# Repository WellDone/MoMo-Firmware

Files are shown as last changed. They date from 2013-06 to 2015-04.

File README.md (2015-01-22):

# WellDone MoMo Hardware and Firmware

A product of [WellDone.org](http://www.welldone.org).



Introduction and documentation available at https://momo.welldone.org

## License ##

Copyright 2015 WellDone International, all rights reserved.

MoMo hardware designs are released under the [CERN Open Hardware License v.1.2](http://www.ohwr.org/attachments/2388/cern_ohl_v_1_2.txt)

Firmware and software tools are released under the [GPLv3](http://www.gnu.org/licenses/gpl.html) Open Source license.

See the LICENSE file for more details.

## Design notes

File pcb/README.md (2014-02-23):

# MoMo Printed Circuit Boards
This directory contains all of the MoMo PCB files as well as scripts used to convert them into production data.
All boards must use EAGLE CAD for layout in order to be compatible with our production scripts.

## PCB Layout
The MoMo build system includes a set of python based tools used to automatically generate production files, BOMS 
and cost estimates from EAGLE board files.  In order for a board to be compatible with these scripts, it
must be made to conform with the following requirements.

EAGLE Attributes are used to tag each part and board with metadata that enables the scripts to look up
information on the part using the Octopart API and to generate a BOM.  Each part should have one of following attributes:

 * _DIGIKEY-PN_ - This should contain the Digikey part number for this part.  If there is not a digikey part number, is should
be left blank or non existent
 * _MPN_ - This is the Manufacturer's part number for the part.  Either MPN or DIGIKEY-PN must be set for every part on the board that
should be populated.
 * _MANU_ - The manufacturer's name.  If MPN is used to specify the part, MANU should be specified as well.
 * _FOOTPRINT_ - If the part does not have a standard SMD footprint link 0402, 0603, etc, they FOOTPRINT should be explicitly defined so
 that it can be used to create a BOM automatically.  If this is a through hole part, the footprint should be given as "Through Hole"
 * _DESC_ - If the part cannot have a generic description made for it (currently only works for Resistors, Capacitors and Inductors)
 then the explicit description should be given in this attribute.

###Assembly Variants
In order to save on PCB fabrication costs, sometimes a single circuit board will be made flexible so that it can be customized at assembly
time by simply change or not populating certain parts.  Each different way the same board can be assembled is called an Assembly Variant.

If a board has several assembly variants, this should be indicated by specifying certain attributes on the board.  An assembly variant can 
either populate a certain part, not populate a certain part or replace a part with a different one.  To do this, change the DIGIKEY-PN or MPN attribute for the part to contain -VARIANT where variant is the name of the assembly variant.  A part with only DIGIKEY-PN (or MPN) set will be assumed to be populated
in every assembly variant. A part with DIGIKEY-PN-VAR1 and DIGIKEY-PN-VAR2 will be populated only in Assembly Variants VAR1 and VAR2.  

A part with DIGIKEY-PN will be populated in every assembly variant except those that have a DIGIKEY-PN-VAR1 with an empty value.  This
means that the way to not populate a certain part in an assembly variant is to define its part number to be blank.  For library parts
that contain a default DIGIKEY-PN value that is not deletable, this is the only way to not populate a part in an assembly variant.

####Changing Part Values in Different Assembly Variants
Often a different assembly variant will not just populate or depopulate a part, but will change a part's value in order to achieve the desired effect.  
For example, a buck regulator design that can be configured to output either 3.6 or 5V depending on the assembly variant may require just changing the feedback resistor value.
In order to do this, the value should be specified as a VALUE attribute with the appropriate -VARIANT name.  So, if there are 2 assembly variants, 5V and 3V and a resistor is 10K in the 
5V version and 15K in the 3V version, the resistor should have the following two attributes:
VALUE-5V = 10K
VALUE-3V = 15K
The actual value of the part may be set to anything since it will be overriden by these attributes.  It is recommended that the actual part value be set to 'varies' so that the 
schematic's intent is not confusing.
###Global Attributes
Every board must define the following global attributes.  These should be defined on the Board, not the Schematic, under Edit->Global Attributes:

 * _[VARIANT]_ - for each assembly variant (if there is only one, nothing must be done) with value ASSY-VARIANT.  The attribute name is the variant name
 * _WIDTH_ - the width of the board (in inches)
 * _HEIGHT_ - the height of the board (in inches)
 * _REVISION_ - a tag specifying the revision level of the board
 * _PARTNAME_ - a name for the board that will be used to generate file names

###Required Configuration
In order to use these scripts you need to configure the location of the Eagle binary on your computer in /config/settings.local.json.  Use the template provided in:
settings.global.json

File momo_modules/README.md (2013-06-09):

### Code for individual MoMo component modules

All modules must implement the [Module Interconnect Bus (MIB)](http://github.com/WellDone/MoMo-Firmware/wiki/Module-Interconnect-Bus-(MIB\)) over I2C.

* `mainboard` (pic24) - The main controller module
* `field_service_unit` (pic24) - The USB<->I2C bridge used to service MoMos in the field.

### Shared Code

* `shared/picXX` - This code is specific to the picXX (i.e. pic12 or pic24) processor, but does not contain code specific to an individual module.
* `shared/portable` - This code (and anything it includes) should be able to run on EITHER an 8-bit pic12 or a 16-bit pic24.

### Source Directory Structure Guidelines

Source code sub-directories are categorized by the abstraction level and functionality goal of the code that lives in each directory.

* `Core` - This is where the core functionality lives.  This includes all top-level functionality and app-wide shared state/#define headers.
* `Debug` - This is code that deals directly with the processing of commands when the device is connected to a debugger / UART device.
* `Diagnostics` - Here there be monsters.  This is for self-test code and the like.
* `Modules` - Every .h/.c pair in Modules is responsible for managing a single, discrete hardware component.
* `Util` - As the name suggests, this is for pure-software utility functions.
* `main.c` - The program entrypoint of course.  This should remain as lightweight as possible.

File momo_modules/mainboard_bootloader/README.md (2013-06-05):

### WellDone MoMo Mainboard Firmware

* This code should be compiled using Microchip's [XC16](http://www.microchip.com/pagehandler/en_us/devtools/mplabxc/) compiler for 16-bit PIC24 devices.
* It has been tested on version 1.11 of the compiler.
* The approved build-compile-test system is to use [Ceedling](http://throwtheswitch.org/).  An introduction to using ceedling for TDD in embeded PIC environments can be found [HERE](http://spin.atomicobject.com/2012/10/22/getting-started-with-tdd-for-microchips-pics/)
* Unit and functional test scaffolding is forthcoming - we expect to support both the Microchip PIC Simulator and in-device physical test definitions.

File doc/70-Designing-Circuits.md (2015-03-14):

# Working with Printed Circuit Boards
The MoMo framework includes a number of tools that simplify the process of designing and assembling printed circuit boards.  These tools lets you automatically generated Bill of Materials documents, price your board at prototype and production quantities and generate all of the required production files for getting the board fabricated and assembled.  All of these products are built from your board layout file containing attributes describing all the required metadata.  This section details how to use the tools and how to design your boards to take advantage of the automatic MoMo PCB build system.

## Getting Started
There are a number of steps that take you from having a PCB layout to actually having that board assembled and in your hands (or those of your customers).  

- **(Supported)** You need to match all of the parts you chose with a component database and generate a Bill of Materials (BOM) document that you can use to buy all of the components for your board.
- **(Supported)** You may want to have multiple assembly variants of the same board, so you'll need a way to make appropriate BOMs and assembly drawings for each variant.
- **(Supported)** You need to generate gerbers and drill files from your board to send to the pcb fab for the board to get made.
- **(Supported)** You need to generate assembly drawings so that you can get the board populated with components from your BOM.
- **(Supported)** You need to figure out how much it will cost for your board in many different quantities and where you should buy your parts.
- (Support planned) You may want to generate a 3D model of your board to use to design the enclosure and make sure everything fits.
- (Support planned) You may need to generate pick and place instructions for automated assembly.

Each of these steps takes time and is error prone, contributing to the cost of your design by increasing the engineering time required to make it.  Included in `pymomo` is a suite of tools that automate each of these steps, reducing errors and saving time.  

In order to make this possible, you need to use a compatible ECAD program and you need to annotate your board with a minimum of metadata so that our automated tools know how to generate all of the required files from generic templates.  The way this annotation takes place depends on what ECAD system you use and is described for each supported program in one of the sections below.

### Required Board Metadata
Each board file is required to specify the following attributes, which are used at various points in the build process to generate output files like assembly drawings, BOMs and Gerbers. The specific way you need to set the attributes varies by ECAD program and is documented in the section on each supported program.

- Height: (number) The height (y dimension) of the board in the units specified in Dim_Units
- Width: (number) The width (x dimension) of the board in the units specified in Dim_Units
- Dim_Units: (text) The units for Width and Height (e.g. inches, mm)
- Company: (text) A string identifying the company or individual that made this board
- Revision: (text) A string specifying the version or revision number of this board.  This can be an arbitary string and is not forced to conform to any specific format.
- Fab_Template: (text) A string specifying what kind of board this is (two layer, 4 layer, etc).  It must correspond to the name of a template defined for your ECAD program, see the section on your ECAD program for the predefined templates.

### Required Component Attributes
In order to produced useful BOMs and quote board prices, we need to be able to match each component on the board with an online database of physical parts that could be purchased from a distributor.  This can be done in two ways.  Either you can supply a manufacturer and manufacturer's part number for a component, or you can supply a distributor's name, like Digikey or Arrow and their part number for the component.  These are the only attributes that are required per part.  

The rest of the information needed for generating BOMs can be looked up but if you would like to override it with your own values, you can define the following optional attributes that will be used instead of what is found in the database:

- Description: (text) a brief description of the component such as "PIC 24F16KA101 8-bit microprocessor"
- Footprint: (text) a text identifier for the type of package that the component comes such as SOT-23 or SMD 0402

Some standard packages are automatically inferred from information provided by the ECAD program and more will be added in the future.  If you don't like the wording of the package in the BOM, you can override it by using the FOOTPRINT attribute.  Not all online databases provide description information so it can be useful to set that attribute as well.

### When Are Identifiers Considered Identical?
A lot of the time there could be ambiguity over whether two words are the same.  For example, is "Digi-Key" the same distributor as "DIGIKEY"?  It's likely that the user intended for them to be the same, but they are not identical strings, making it difficult for a program to determine the user's intent.  In `pymomo.pcb` a consistent policy is applied to determine whether two text strings like manufacturer names or part numbers are identical.  First, all spaces, '_' and '-' characters are stripped out of both strings and they are converted to lowercase.  Then, these canonicalized strings are compared to see if they are identical.  So, "Digi-Key" matches "DIGIKEY" which also matches "DIGI KEY" but does not match "Digi,key".

### Supported Component Databases
Currently the only supported component database that can be used is [Octopart](http://octopart.com).  It is easy to add other databases and support is planned for Mouser's API as well. This means that to use the BOM matching features you currently need an Octopart API key (there's a free tier!).  `pymomo.pcb` looks for the key as an environment variable named `$OCTOPART_KEY`.  All results from any component database is cached for the maximum amount of time permitted by the TOS of the serivce to reduce latency and the total number of requests the program makes.  This caching process is transparent to the user and results returned from the cache are indistinguishable from those returned directly from the database.  

## Interacting with PCB Board Files
All of the objects that deal with circuit boards are defined in `pymomo.pcb` and accessible using the `momo` tool.  This section walks through some common tasks using the momo controller pcb as an example:

```shell
> ls $MOMOPATH/pcb/momo_modular/controller
controller.brd	controller.sch
```

### Matching Parts with an Online Database
```shell
> momo pcb CircuitBoard $MOMOPATH/pcb/momo_modular/controller/controller.brd match_status
True
```

`match_status` returns whether or not all of the parts on this board could be matched to an online database based on their embedded metadata.  You can get more details about the status of each part by using ```match_details```

```shell
> momo pcb CircuitBoard $MOMOPATH/pcb/momo_modular/controller/controller.brd match_details
Q1: Matched to a unique item
Q3: Matched to a unique item
Q2: Matched to a unique item
U5: Matched to a unique item
U4: Matched to a unique item
U1: Matched to a unique item
U2: Matched to a unique item
JP1: Matched to a unique item
C13: Matched to a unique item
JP2: Matched to a unique item
JP5: Matched to a unique item
JP4: Matched to a unique item
C15: Matched to a unique item
R13: Matched to a unique item
XT1: Matched to a unique item
C9: Matched to a unique item
C3: Matched to a unique item
C5: Matched to a unique item
C4: Matched to a unique item
R4: Matched to a unique item
C20: Matched to a unique item
R7: Matched to a unique item
R1: Matched to a unique item
D2: Matched to a unique item
```

This tells us that all of the parts were matched to exactly one physical part in the online database, indicating that there was no ambiguity in the match process and the board is ready for BOM generation.

### Looking up a Part 
You can look up any part on a board to see who sells it and how much it costs.  For example lets see what part U5 on the controller board does:
```shell
> momo pcb CircuitBoard $MOMOPATH/pcb/momo_modular/controller/controller.brd find U5
Part U5
 Manufacturer: MICRON
 MPN: M25PX80-VMN6TP
 Distributor: Digikey
 Distributor PN: M25PX80-VMN6TPCT-ND
 Package: SOP08 Package (0 pins, 8 pads)
 Location: (55.9816 millimeter, 19.6088 millimeter) rotated 90 degrees
 Description: M25PX80 1MB Serial Flash
```

It looks like this part is a flash memory chip.  Now let's see how much it costs and who sells it:

```shell
> momo pcb CircuitBoard $MOMOPATH/pcb/momo_modular/controller/controller.brd lookup U5
Manufacturer: Micron
MPN: M25PX80-VMN6TP
Description: NOR Flash Serial-SPI 2.5V/3.3V 8Mbit 1M x 8bit 8ns 8-Pin SO N T/R
Offers
  Seller: Verical
    Packaging: None
    Stock: 7500
    Minimum Order: 2500
    Breaks
      2500: 0.60000
  Seller: Digi-Key
    Packaging: Cut Tape
    Stock: 18208
    Minimum Order: 1
    Breaks
      1: 0.86000
      10: 0.78100
      25: 0.77120
      50: 0.76680
      100: 0.68540
      250: 0.67968
      500: 0.66960
      1000: 0.64548
  Seller: Digi-Key
    Packaging: Custom Reel
    Stock: 18208
    Minimum Order: 1
    Breaks
      1: 0.86000
      10: 0.78100
      25: 0.77120
      50: 0.76680
      100: 0.68540
      250: 0.67968
      500: 0.66960
      1000: 0.64548

 <output truncated>
```

The `lookup` function returns all of the sellers for a particular part known to the chosen online database.  

### Generating a BOM
Once a board has all of the required metadata, it can be used to automatically generate a BOM.  Currently, `pymomo` only supports generating excel style (.xlsx) BOMs since these are standard but support is planned for template based generation of BOMs in other formats.  First, let's make sure the BOM lines look right:

```shell
> momo pcb CircuitBoard $MOMOPATH/pcb/momo_modular/controller/controller.brd bom_lines
6 10K Resistor: ['R1', 'R2', 'R3', 'R5', 'R9', 'R18']
2 1 ohm Resistor: ['R4', 'R20']
5 100K Resistor: ['R6', 'R10', 'R11', 'R13', 'R19']
7 510K Resistor: ['R7', 'R8', 'R12', 'R14', 'R15', 'R16', 'R17']
8 100 nF Capacitor: ['C1', 'C2', 'C5', 'C10', 'C11', 'C12', 'C16', 'C17']
1 33 pF Capacitor: ['C3']
1 10 pF Capacitor: ['C4']
4 1 uF Capacitor: ['C6', 'C9', 'C19', 'C21']
2 18 pF Capacitor: ['C13', 'C14']
2 10 uF Capacitor: ['C15', 'C18']
1 22 pF Capacitor: ['C20']
2 Diode: ['D2', 'D3']
1 XC6504 Linear Regulator 2.8V: ['U1']
1 PIC24FJ64GA306 Microcontroller: ['U2']
1 RN4020 Bluetooth 4.0 Module: ['U4']
1 M25PX80 1MB Serial Flash: ['U5']
1 Quartz Crystal (Radial Can): ['XT1']
1 6 Pin Vertical Male Header: ['JP1']
1 6-pin female R/A header: ['JP2']
1 MicroUSB-B Receptacle : ['JP4']
1 R/A Shrouded 2 pin connector: ['JP5']
1 N-Channel MOSFET 2N7002P: ['Q1']
2 P Channel MOSFET: ['Q2', 'Q4']
1 PNP Transistor: ['Q3']
```

The `bom_lines` function returns a list of strings for each BOM line with the line's description and, quantity and reference designators.  If everything seems fine, you can export a BOM using:
```shell
> momo pcb CircuitBoard $MOMOPATH/pcb/momo_modular/controller/controller.brd export_bom $OUTPUT_FILE --format excel
```

`$OUTPUT_FILE` should be the path to the excel file that you want to generate.  If there are any errors or warnings in the process of generating the BOM they are noted in the excel file by default to make sure that you don't accidentally get a bad BOM.

### Checking For Errors
The program keeps track of any missing required attributes that it finds as well as common mistakes and can report these to you using the `get_errors` and `get_warnings` functions, which both return a list of strings.

```shell
> momo pcb CircuitBoard $MOMOPATH/pcb/momo_modular/controller/controller.brd get_errors
ERROR on attribute/part company: Attribute was empty or not defined
ERROR on attribute/part units: Attribute was empty or not defined
```

Here the system is telling us that we forgot to define a company and dim_units attribute on our board. In generated BOMs, the spots where the information is needed will be filled with obvious placeholder values until we fix this.  The program does its best to work around any missing information but always makes a note of it so that you know what it's doing.

### Pricing Parts and Boards
If you want to figure out how much a certain part costs at various quantities, you can use the `price` function.  For example, to figure out how much part U5 costs for 1 unit from Digikey, you can do:

```shell
> momo pcb CircuitBoard $MOMOPATH/pcb/momo_modular/controller/controller.brd require_distributor Digikey price U5 1
$0.86 from Digi-Key as Custom Reel
```

More information on setting requirements about what types of sellers can be used to generate prices is discussed in the section on Creating a Price Model.  We can just as easily figure out how many 1000 parts would cost (including any saving due to price breaks).

```shell
> momo pcb CircuitBoard $MOMOPATH/pcb/momo_modular/controller/controller.brd require_distributor Digikey price U5 1000
$0.65 from Digi-Key as Custom Reel
```

To figure out how many an entire board costs, you can use the `detailed_prices` function.  For example, let's say that we want to buy enough parts for 10 boards from Digikey with 10% excess to account for assembly losses.  Since it's a small number of units, we don't want to consider any Digi-Reel custom reels.  It's most clear to specify the price requirements one at a time, we start by opening a momo shell and specifying our requirements:

```shell
> momo pcb CircuitBoard $MOMOPATH/pcb/momo_modular/controller/controller.brd
(CircuitBoard) require_distributor Digikey
(CircuitBoard) exclude_packaging "Custom Reel"
(CircuitBoard) detailed_prices 10 10
P Channel MOSFET: $4.32 from Digi-Key as Cut Tape
1 ohm Resistor: $0.64 from Digi-Key as Cut Tape
Diode: $3.76 from Digi-Key as Cut Tape
10 pF Capacitor: $0.13 from Digi-Key as Cut Tape
510K Resistor: $1.06 from Digi-Key as Cut Tape
RN4020 Bluetooth 4.0 Module: $88.40 from Digi-Key as Tray
10K Resistor: $0.92 from Digi-Key as Cut Tape
10 uF Capacitor: $3.42 from Digi-Key as Cut Tape
18 pF Capacitor: $0.48 from Digi-Key as Cut Tape
XC6504 Linear Regulator 2.8V: $3.91 from Digi-Key as Cut Tape
100 nF Capacitor: $2.02 from Digi-Key as Cut Tape
6-pin female R/A header: $7.26 from Digi-Key as Bulk
MicroUSB-B Receptacle : $4.33 from Digi-Key as Cut Tape
1 uF Capacitor: $2.64 from Digi-Key as Cut Tape
PIC24FJ64GA306 Microcontroller: $32.20 from Digi-Key as Tray
Quartz Crystal (Radial Can): $1.75 from Digi-Key as Bulk
PNP Transistor: $0.95 from Digi-Key as Cut Tape
33 pF Capacitor: $0.13 from Digi-Key as Cut Tape
N-Channel MOSFET 2N7002P: $1.35 from Digi-Key as Cut Tape
22 pF Capacitor: $0.13 from Digi-Key as Cut Tape
6 Pin Vertical Male Header: $2.05 from Digi-Key as Bag
M25PX80 1MB Serial Flash: $7.81 from Digi-Key as Cut Tape
R/A Shrouded 2 pin connector: $1.53 from Digi-Key as Bulk
100K Resistor: $0.76 from Digi-Key as Cut Tape
(CircuitBoard) quit
```

If we don't care about the details of how much each part costs but just want the total price, we can use the `total_price` function

```shell
momo pcb CircuitBoard $MOMOPATH/pcb/momo_modular/controller/controller.brd total_price 100 0
total: 1290.11
unit: 12.90
```

### Creating a Price Model
Price a board is a little complicated.  Each part could come from several distributors and each distributor has a finite amount of stock.  Parts come in various kinds of packaging as well like Reels, Cut Tape and Trays.  Part of pricing a board is setting up preferences for which distributors to buy from and what kinds of packaging to look for or avoid.  The set of requirements you have for sellers to be considered valid is called the Price Model by `pymomo.pcb`.  You can build it up little by little using the following functions:

```
exclude_distributor
require_distributor
exclude_package
require_package
require_stock
```

The `require_*` and `exclude_*` functions respectively whitelist and blacklist certain distributors and packaging types.  For example if you call:

```
(CircuitBoard) exclude_distributor Mouser
(CircuitBoard) require_package "Cut Tape"
```

Then you are saying that you only want to look at prices that come in Cut Tape and are not from Mouser.  You can also choose to only show prices where there is enough stock to cover your entire order from a single distributor using the `require_stock` function.  If you make a mistake, you can clear the current Price Model and start over using `clear_pricemodel`. The Price Model is a property of the CircuitBoard context that created it and will apply to all future pricing requests on that CircuitBoard until it is cleared.  

### Generating Production Files for Fabrication and Assembly
Once you have your board file tagged with all of the required metadata as described in the section on Supported ECAD Programs, you can use `pymomo.pcb` to automatically generate production files (Gerbers, Excellon Drill Files, Assembly Drawings and BOMs) for fabrication and assembly.  To do so, just create a CircuitBoard object and call `generate_production` passing the name of the directory you would like to create to contain all of the fabrication and assembly files.  For example,

```shell
$ momo pcb CircuitBoard $MOMOPATH/pcb/momo_modular/controller/controller.brd generate_production ~/controller
$ ls ~/controller/fabrication/
README.txt	controller.crm	controller.plc	controller.stc
controller.cmp	controller.drd	controller.sol	controller.sts
$ ls ~/controller/assembly/
BOM_controller.xlsx	controller.ps
```

The created production files include:

- GERBER format files for each layer on your board
- A README.txt that contains descriptions for each gerber, your company, part name, revision, etc.
- A BOM for your board
- An assembly drawing
- A zip file containing all of the fabrication (<part name>_fab.zip) related files for uploading to your board house.

### Templates Used for Production Files
In order to generate production files, you need to embed information into your board about the layers that you want generated.  For example, is your board a standard 2 layer design with top and bottom copper and soldermask and a top silkscreen or do you want a 4 layer board?  This is done by embedding a fab_template attribute into your board as described in the section on your particular ECAD program.  The template name is used to look up how many Gerber layers to create and what logical layers to include in each gerber file.

## Supported ECAD Programs
The `pymomo.pcb` PCB build system is completely agnostic to where the information it needs comes from, so it does not depend per-se on what ECAD program you use to design your circuit.  However, it needs a way to extract the information from your board files.  We have built adapters that work automatically with the following popular ECAD programs.  If you use another program you could consider writing an adapter module to make it work with `pymomo.pcb`.  Pull Requests are always appreciated.

### EAGLE CAD
Eagle is a very popular schematic capture and layout program and is fully supported by `pymomo.pcb`.  The build system works with EAGLE .brd board files and to be suitable you need to annotate the boards using EAGLE attributes as described in this section.  You also need to be using a new enough version of EAGLE that uses their XML file format.  

#### Specifying Global Board Information
You need to set the following 'Global Attributes' on your Eagle Board (not the schematic, the board itself).  You can set an attribute using the menu item Edit -> Global Attributes.  The attributes are described in the above section on required attributes.  This section just lists the names that each attribute should have (all attributes in Eagle are stored as uppercase strings).

- HEIGHT: Board Height
- WIDTH: Board Width
- DIM_UNITS: Height/width units
- COMPANY: Your company or name
- REVISION: An identifying specifying the revision of this board.
- FAB_TEMPLATE: The template describing the layers on your board (i.e. two_layer, 4_layer, etc).

#### Specifying Multiple Assembly Variants
If your board has multiple assembly variants, you need to specify what they are by defining a Global Attribute (see previous section) that contains the name of each variant.  The names can be any string you want that forms a valid EAGLE attribute identifier. Each variant should be defined by creating an attribute whose name corresponds to that name of the attribute and whose value is 'ASSY-VARIANT'.  Remember that assembly variant names are not case sensitive.  If you only have one assembly variant nothing needs to be done.

For example, to define a board with two assembly variants (solar and battery), define two global attributes as follows:

```
SOLAR: ASSY-VARIANT
BATTERY: ASSY-VARIANT
```

You can specify assembly-variant specific part information by appending the assembly variant name to a part's attribute using a hyphen, so if you want to make a part that is populated in the SOLAR variant but not in BATTERY (e.g. the solar panel), you could define two attributes on that part as follows:

```
POPULATE-SOLAR: YES
POPULATE-BATTERY: NO
```

This part will be automatically included as a populated part when you deal with the SOLAR variant but will be listed as an unpopulated part in the BATTERY variant.  You can also specify default values that apply at all variants except when overridden by specifying the attribute without a variant extension.  So the above example could also be written as:

```
POPULATE: YES
POPULATE-BATTERY: NO
```

The default attribute applied to all assembly variants would be to populate the part but, only for the battery variant, it would be overriden to not populate the part.  The following per-component metadata can be overwritten in this way:
- VALUE
- POPULATE
- DIST
- DIST-PN
- DIGIKEY-PN
- MANU
- MANU-PN
- DESCRIPTION

#### Specifying Component Metadata
In order to support BOM generation and the creation of placement files and assembly drawings, each component on the eagle board file must have a minimum out of metadata that allows it to be matched with an online component database and the rest of the information looked up.  Specifically, you have to provide either a distributor's name and part number or a manufacturer's name and part number.  These are specified using Eagle attributes attached to each component *on the board file*.  The list of valid attributes is:

- DIST - a distributor's name that carries this part
- DIST-PN - the distributor's part number for this part
- DIGIKEY-PN - a shortcut that sets DIST=Digikey and DIST-PN to this value
- MANU - The manufacturer
- MPN - The manufacturer's part number
- POPULATE - [yes | no], whether this part should be populated.  All parts are assumed to be populated unless a POPULATE=no attribute is specified.
- DESCRIPTION - a short textual description
- FOOTPRINT - the footprint for this part (i.e. SOT-23, SMD 0402, Through Hole, etc)

You can override some of these values per assembly variant as described in the previous section.

#### Supported Fabrication Templates
Currently, only two layer boards are supported without extra configuration by specifying 'two_layer' in the FAB_TEMPLATE global attribute.  This will create a board with the following gerber layers (composed of the indicated EAGLE layers):

- Top Soldermask: ["tStop"]
- Top Silkscreen: ["Dimension", "tPlace", "tNames"]
- Top Solderpaste: ["tCream"]
- Top Copper: ["Top", "Pads", "Vias"]
- Bottom Copper: ["Bottom", "Pads", "Vias"]
- Bottom Soldermask: ["bStop"]

The assembly drawing is in PS format since that is what EAGLE supports exporting and it includes the following layers:
["tPlace", "tNames", "tDocu", "Document", "Reference","Dimension"]

You can create your own eagle templates and use them in your boards by editing the eagle.json file in the config directory of pymomo.

#### Finding Your Installed Eagle Version
If you are not using Mac OS X you need to add the EAGLE executable to your $PATH in order for `pymomo.pcb` to be able to find it and use it for generating fabrication files.  You don't need to do this for BOM generation since that is done by parsing the EAGLE board files directly. 

If you are using Mac OS X and you installed Eagle to the standard location using the EAGLE installer (/Applications/EAGLE-X.Y.Z) then you don't need to do anything.  Pymomo will find eagle for you and automatically use the latest version.  If you want to force pymomo to use a particular version then you can add that version to your $PATH and pymomo will preferentially use what it finds in the path over what it finds looking on its own.

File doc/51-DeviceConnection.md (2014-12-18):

## Programming Your MoMo
This section documents the process of getting the MoMo build environment set up and ready for hardware programming and testing.  The build system and support tools are cross-platform on Mac OS X, linux and Windows but are only tested extensively on Mac OS X and linux.  Bugfixes and patches are always gratefully accepted.  Windows users will need to install some supporting programs that are installed by default on Mac OS X and Linux, so read the [Windows Installation](https://github.com/WellDone/MoMo-Firmware/wiki/windows-installation) first.

###Step 1 - Clone the Repository
Make sure git is installed on your computer and then clone our repository and checkout the dev branch with the following commands:
```shell
git clone https://github.com/WellDone/MoMo-Firmware.git
git checkout dev
```

###Step 2 - Run Vagrant or Develop Locally
There are two options here.  You can either:

* Install [VirtualBox](https://www.virtualbox.org/) and [Vagrant](http://www.vagrantup.com/downloads.html) and then run `vagrant up` from the repository directory.  This will download a Virtual Machine (VM) (note: the initial download is large) and provision it with all of the development requirements.  Subsequent steps below can be run through `vagrant ssh` which creates a virtual shell connected to the running VM.  At this point everything should be set up for you.
* OR Install the development dependencies locally.  There may be some idiosyncracies to work through, but you should be able to mostly follow the instructions [here](http://www.github.com/WellDone/MoMo-Firmware/wiki/Development-Dependencies).

### Looking Around
```shell
> ls
config  doc  momo_modules  pcb  README.md  tools
```

A brief overview of what is what:

- config - reference information about pcb layouts and build constants.  Templates for module skeleton code is stored here as well
- doc - assorted datasheets and reference information.  Not terribly well organized currently
- momo_modules - all module firmware is stored under these directories.  momo_modules/shared contains shared library code.  Other directories correspond to a single firmware image each.
- pcb - all circuit board
- tools - all of the support infrastructure is stored in the tools directory.  You should add tools/bin to your PATH for easy access to the support tools.  Most of the build system is implemented as a python package pymomo which lives in tools

### Step 3 - Required Configuration
Make sure `gpsim` and `sim30` are in your PATH by running `which gpsim` and `which sim30`.  If you need to use the pcbtool hardware support program, you'll also need `eagle` ([Eagle Cad](http://www.cadsoftusa.com/)), but if not it isn't required.

### Checking that Everything Works
Assuming that you added tools/bin to your PATH variable, you can use the modtool program to talk to a connected MoMo unit.  Plug in your MoMo FSU into a USB port and plug the other side into a MoMo unit.  Power the MoMo unit and you should see a green light illuminate on the FSU.  Usually the momo tools will be able to guess which port your MoMo is plugged into, if not you will need to know the device or com port that corresponds to the MoMo FSU.  

On linux it is probably:
```shell
/dev/ttyUSB0
```

On Mac OS X is is probably:
```shell
/dev/tty.usbserial.SOMETHING
```

On Windows is is probably COM2 or COM3 depending on how many other serial ports you have.  If you are using cygwin (which we don't recommend), then the serial port will show up probably as something like:
```shell
/dev/ttyS2
```

**Note:**  On OS X Mavericks, apple broke FTDI USB-Serial adapter support so you need to implement the workaround described here to install a working driver: http://forum.arduino.cc/index.php?topic=198539.0

If you need a driver for the MoMo FSU, it uses the FTDI 230X chip which has drivers here:
http://www.ftdichip.com/FTDrivers.htm

In what follows, _PORT_ will refer to the device or COM port as listed above that corresponds to your computer.  Try to access the MoMo and list all of its attached modules to make sure everything is working using the command below: 

```shell
modtool list
0: pv_mod
1: Whatever
2: Something else
```

**Note:** Windows users may need to add 'python' in front of commands like 'modtool' in order to be recognized.

If the command finishes without error, you are completely set up.  If it throws an exception then it was not able to guess your COM port correctly and you'll have to specify it explicitly, i.e.:
```shell
modtool list -p PORT
0: pv_mod
1: Whatever
2: Something else
```

### Step 4 - Read up on how to use all of the tools
There is documentation for all of the support tools that help you use MoMo.  Read about them in the [tools section](#tools)

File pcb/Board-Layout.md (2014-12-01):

# Circuit Board Layout Guidelines
This document specifies rules and best practices for laying out and routing MoMo circuit boards.  It should be followed for all MoMo boards.  Additions to this document will be made as new guidelines are needed or board specifications change.

## Feature Sizes
- All silkscreen label text should be size 32 mils in EAGLE.  This is large enough to be legible but not so large as to make placement too difficult.
- Minimum trace/space is 6 mil.  When possible, route with larger trace/spaces but that only really makes sense if you can route the entire board with larger traces.  Power containing traces should be sized according to power demands but at least 12 mils.

## Fixed Locations
Screw holes are required on the short edge of each MoMo module for proper assemble.  The holes should be .132" in diameter and spaced .128" in from the edge of the boards.  The should be spaced 1.1" apart from each other.  There will be a nylon standoff around the screw hole, meaning that the exclusion are around the screw hole is: 0.25" in diameter.  The two sets of holes should be 3.744" away from eachother center to center.  Given a 2" long module, that gives 0.128" away from the module edge.

## Miscellaneous

- All capacitors unless required should be 0402 from Eagle's RCL library C_US 0402K (Kemet for reflow soldering)
- All resistors should be MLCC 0603 standard 1% chip resistors unless other specs are required.

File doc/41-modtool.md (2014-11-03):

##modtool - Working with MoMo hardware modules

modtool is a program that sends commands to MoMo hardware modules and allows you to test them, debug them and program them.
It is written in python and all of its functionality is built on top of the pymomo.commander library.  If you are comfortable
in Python and looking to script your MoMo module, you should jump directly to using pymomo.commander in Python scripts.  If
you are looking for a command line application to simplify common MoMo related tasks, modtool is right for you.  Modtool
runs equally well on Mac OS X, Linux and Windows provided that you have installed all of its library dependencies.

### Introduction
modtool can do the following things:
 * Reprogram any MoMo module with new firmware
 * Run premade hardware testing scripts on any MoMo module
 * List attached modules and interact with them
 * Configure any MoMo module
 * Debug MoMo modules
 * Dump MoMo sensor or system logs

### Using Modtool
modtool is a command line program that lives in tools/bin.  If you have added tools/bin to your $PATH, you can run modtool
by executing:

```shell
$ modtool help
```

All of the modtool commands are documented in the internal help system, which can be accessed by using:

```shell
$ modtool help subcommand
```

### Connecting Your Hardware
Using modtool requires that you connect your MoMo device to your computer using a bridge between your computer
and the MoMo bus (MIB).  This could be done using a MoMo Field Service Unit (FSU) that connects to the MoMo and
to the USB port of your computer, or it could be done over bluetooth.  In either case, your fsu will show up as a
COM port and modtool interacts with the FSU by sending serial commands to that COM port.  Modtool will try to guess
which COM port your FSU is plugged into but if it cannot do so for some reason (like you have multiple virtual COM ports),
then you will have to specify the correct port.  You can do this by passing a -p <COM PORT or device file> parameter to
modtool.  

To verify that everything is working, attach your MoMo to the computer and run:
```shell
$ modtool list
```

If the command finishes correctly, your MoMo is correctly attached and modtool can find it.  If there is a communication error,
try passing the correct COM port.  On linux this could look like:
```shell
$ modtool list -p /dev/ttyUSB0
```

On Windows it could be:
```shell
$ modtool list -p COM3
```

You will need to replace those port identifiers with the correct ones for your system.  Once you have verified connectivity, 
you can use all of modtool's features to interact with your MoMo device.

### Modtool Commands

#### Listing and Describing MoMo modules
Each MoMo unit is composed of various boards that all perform specific tasks.  You can see what boards are attached to your 
MoMo controller unit by using:
```shell
$ modtool list
```

To get more information about a given module use:
```shell
$ modtool info <INDEX>
```
where INDEX is the index for the module given in the result of the 'modtool list' command.

### Reflashing a Module
If you want to update the firmware code running on an attached MoMo module, you can do so using the modtool reflash command.
You will have to specify which module to reflash using either its name or its address.  You can find the names and addresses
of all the attached modules using the modtool list command.  To reflash a module by address use:
```shell
modtool reflash -a N <HEXFILE>
```

To reflash by name:
```shell
modtool reflash -n gsm_mod <HEXFILE>
```

The reflash command clears the controller's firmware cache to make sure there's room, pushes the hex file to the controller,
finds the module by either its name or address and then sends an RPC call to that module for it to reflash itself.  The command
waits for the reflashing to finish before returning.  Note that since the module cannot communicate during reflashing, the wait
time is just a timer based on the maximum time that the reflashing could take.  You should not remove power from your MoMo unit
or try to use it during the reflashing process.  Doing so will definitely cause the firmware to be programmed incorrectly and
could potentially brick the module.  It is, by design, very hard to brick a MoMo module however so you should be safe.

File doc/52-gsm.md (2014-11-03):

## Using the GSM module

This tutorial assumes that you have a programmed v5 GSM module and a working connection from your PC to the MoMo.  It will introduce the GSM module and outline steps for setting it up.

### Physical setup

There are a few steps required to prepare the GSM module for transmission:

- Attach an antenna to the u.FL connector.  Make sure the connector is pushed all the way down and try to avoid having the antenna cable traverse over any of the board electorics
- Insert a Micro SIM card into the SIM card slot - this may require cutting a full-sized SIM or using a SIM Card Punch
- Wrap the entire MoMo in paper (to prevent shorting) and then tin foil from the kitchen (to work around a known issue with GSM transmission RF feedback)

### Hardware RF Feedback Known Issue

With version 5 and earlier GSM hardware, there is a known issue which can cause GSM transmissions to fail.  The symptom exhibited is as follows:

When sending a GSM message, the entire MoMo may reset (you can determine that this has happened by looking at the system log) while openning the GSM module attempts to acquire a network signal.

This won't always happen, but it can cause some frustration when it does.  Luckily, there is a relatively simple workaround:

The issue occurs because the GSM module causes excessive RF feedback to overload the circuitry.  This can be avoided, interestingly, by wrapping the entire device in standard kitchen aluminum foil.  To prevent the foil from causing shorts, the MoMo should first be wrapped in a tube of paper so that none of the metal foil comes in contact with the PCB.

### Testing with GSMTool

There is a command-line program called `gsmtool` in tools/bin that can be used to interact with the GSM module.  This may eventually be replaced by the `momo` tool.

The following is the output of `gsmtool -h` which describes some of what the tool can do:

```
Usage:
    gsmtool COMMAND [ARGS...]
    gsmtool help [COMMAND]

Options:
    -h, --help  show this help message and exit

Commands:
    cmd            Tell the GSM modem to execute an AT command
    debug          Get debug info
    dump           Dump the modem's serial buffer (for debugging)
    help (?)       give detailed help on a specific sub-command
    msg            Send a text message with the content <text> to <dest>
    off            Turn off the GSM modem
    on             Turn on the GSM modem.
  ```
  
  To test that the module is set up and working properly, follow these steps. *NOTE* this assumes that the GSM module is at address 11, replace 11 with the address of the module according to the output of `momo controller enumerate_modules`.
  
  1. Turn on the module `gsmtool on -a 11`, this may take a few seconds.
  2. Check that the module turned on with `gsmtool debug -a 11`, the output should include `module_on: True`
  3. Run an AT command to check that the SIM card is installed correctly: `gsmtool cmd -a 11 AT+CPIN?`, output should be `+CPIN: READY`
  4. Run another AT command to check that the module was able to connect to the network: `gsmtool cmd -a 11 AT+CREG?`.  If the output is `+CREG: 0,2` then the module is still searching for the network, if it is `+CREG: 0,1` then it has successfully registered.  Anything else probably indicates lack of signal (see below) or a bad SIM card.
  5. Run `gsmtool cmd -a 11 AT+CSQ` to check the signal strength.  A sample ouput is `+CSQ: 31,0` - The second number should always be 0, higher is better for the first number (31 is a strong signal).
  6. Finally, run `gsmtool msg -a 11 <number> "<message>"` to send an SMS containing the text <message> to <number>.  For example: `gsmtool msg -a 11 +14155551234 "This is a test of the emergency alert system."`
  7. Check that the message was sent by running `gsmtool dump -a 11` and noticing that there are no errors, then running `gsmtool debug -a 11` and noticing that the module turned itself off.

### Setting up autonomous reporting

Sending SMS messages is all well and good, but that was a lot of steps.  Let's set up MoMo to send messages by itself.  The tool we will use this time is affectionately called `reportinator` and is used to configure the reporting settings on the MoMo controller.

The following sequence tells the MoMo to start reporting to +1-415-555-1234 every hour, using the default aggregate settings (Min and Max over the whole interval, Mean and Count for each step)

```shell
$ reportinator route +14155551234
(12) +14155551234
$ reportinator interval 5
5
$ reportinator start
```

### Configuring reporting settings

Running `reportinator -h` yields:

```
Usage:
    reportinator COMMAND [ARGS...]
    reportinator help [COMMAND]

Options:
    -h, --help  show this help message and exit

Commands:
    aggregates     Get or set the report aggregates.
    flags          Get or set the report flags.
    help (?)       give detailed help on a specific sub-command
    interval       Get or set the reporting interval.
    log            Manage the log of reports, succeeded and failed.
    parse          Parse a report in BASE64 format
    route          Get or set the destination address for reporting.
    send           Send a single report
    sequence       Get the current report sequence.
    start          Start reporting
    state          Get the current state of the autonomous reporting flag.
    stop           Stop reporting
    test
```

Here's an overview of the different settings and commands available:

#### Aggregates

The aggregation / reduce functions to run over each time step, as well as over the entire reporting interval.  Use `reportinator aggregates` to read the current settings, and `reportinator aggregates <step_agg> <bulk_agg>` to set them.  Aggregates are reported and set as integer numbers, but internally they are a bitset with the following possible values:

- 0b00000001 = Count
- 0b00000010 = Sum
- 0b00000100 = Mean
- 0b00100000 = Min
- 0b01000000 = Max

Therefore, an aggregate value of 1 reports only the count, a value of 4 reports only the mean, while a value of 99 reports Max, Min, Sum, and Count (that's 64 + 32 + 2 + 1).

#### Flags

These will probably go unused, but can be set to include static values in every report from this MoMo.  `reportinator flags` to read and `reportinator flags <value>` to write.

#### Interval

How frequently a report should be sent.  `reportinator interval` to read and `reportinator interval <value>` to set. Possible values are:

- 1 = Every Second
- 2 = Every 10 Seconds
- 3 = Every Minute
- 4 = Every 10 Minutes
- 5 = Every Hour
- 6 = Every Day (default)

#### Log

Interact with the report log stored in flash on the MoMo controller.  Possible sub-commands:

- `reportinator log read [<n>]` - Read the last `<n>` entries from the log.  If `<n>` is not specified, read all entries.
- `reportinator log count` - Get the total number of entries in the log
- `reportinator log clear` - Erase the log completely (use with caution)

#### Parse

This command does not interract with an attached MoMo, but rather takes a base64-encoded MoMo report as its first argument and outputs a human-readable version, i.e.:

```shell
$ reportinator parse AgwNAAAAugLAIQAAYQUSGMAhAAAAAGkBAABoAQAAaAEAAGgBAABoAQAAaAEAAGgBAABoAQAAaAEAAGgBAABoAQAAaAEAAGgBAABoAQAAaAEAAGgBAABoAQAAaAEAAGgBAABoAQAAaAEAAGgBAABoAQAAZwEAAA==
version: 2
sensor: 12
sequence: 13
flags: 0
battery charge: 3.79V
diag: 8640, 0
Interval type: hour
         step: 1
        count: 24
Global aggregates:
	count = 8640
	min = 0
	max = 0
Interval Aggregates:
           count    mean
             361       0
             360       0
             360       0
             360       0
             360       0
             360       0
             360       0
             360       0
             360       0
             360       0
             360       0
             360       0
             360       0
             360       0
             360       0
             360       0
             360       0
             360       0
             360       0
             360       0
             360       0
             360       0
             360       0
             359       0
```

#### Route

The destination SMS address for reports.  `reportinator route` to read and `reportinator route <number>` to set.  The number should be of the form `+<cc>xxxxxxxxxx`, i.e. `+14155551234`.  No punctuation or spaces, start with + followed by the country code and then the phone number.

#### Send

Artificially construct and send a report, right now.

#### Sequence

Read the current sequence number which will be embedded in the next report.

#### Start

Start sending reports automatically at the designated interval.

#### State

Read whether or not the MoMo is currently generating regular reports (possible results: `Enabled` or `Disabled`)

#### Stop

Stop sending reports automatically.

#### Test

Run a test on report construction functionality on the attached MoMo.

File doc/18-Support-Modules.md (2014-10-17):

## Field Service Unit

This unit is currently used to control, reflash, and debug MoMo units.  It acts as a bridge between the MoMo's MIB communication protocol and USB.

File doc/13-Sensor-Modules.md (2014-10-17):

## Sensor Modules

Sensor Modules collect information from the physical world around a MoMo.

### MultiSensor

This is the Hulk Hogan of sensor boards.  It can serve many different purposes, and contains circuitry for the following sensors:

- 1 pulse counter
- 3 voltage sensors
- 1 current sensor
- 1 pressure sensor (requires an additional pressure transducer IC component)
- 1 serial comm line

More information about the MultiSensor and how to use it coming soon.

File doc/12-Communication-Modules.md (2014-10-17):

## Communication Modules

A MoMo needs some way to talk with the outside world, so it needs a Comm module.

### GSM Module

This is the first communication module you will encounter.  It contains a quad-band GSM radio and requires a micro-SIM card as well as a uFL antenna.

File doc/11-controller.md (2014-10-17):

## The Controller

This is the brain of any MoMo unit, and is the only module that is absolutely required.  The controller module contains:
- A 16-bit PIC24 MCU.
- 1MB of Flash memory
- A battery connector (which expects 2.8-3.4V DC)
- A battery charging circuit (the charging port expects >100mA from a solar panel or USB charger)

Version 5 of the controller hardware, currently the top of the line, is pictured below.

(image needed)

In this picture, the white connector on the left is for the battery and the port on the right is (optionally) for the charging source.

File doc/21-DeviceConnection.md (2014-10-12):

## Programming Your MoMo
This section documents the process of getting the MoMo build environment set up and ready for hardware programming and testing.  The build system and support tools are cross-platform on Mac OS X, linux and Windows but are only tested extensively on Mac OS X and linux.  Bugfixes and patches are always gratefully accepted.  Windows users will need to install some supporting programs that are installed by default on Mac OS X and Linux, so read the [Windows Installation](windows-installation) first.

###Step 1 - Clone the Repository
Make sure git is installed on your computer and then clone our repository and checkout the dev branch
```shell
git clone https://github.com/WellDone/MoMo-Firmware.git
git checkout dev
```

###Step 2 - Run Vagrant or Develop Locally
There are two options here.  You can either:

* Install [VirtualBox](https://www.virtualbox.org/) and [Vagrant](http://www.vagrantup.com/downloads.html) and then run `vagrant up` from the repository directory.  This will download a VM (note: the initial download is large) and provision it with all of the development requirements.  Subsequent steps below can be run through `vagrant ssh` which creates a virtual shell connected to the running virtual machine.  At this point everything should be set up for you.
* OR Install the development dependencies locally.  There may be some idiosyncacies to work through, but you should be able to mostly follow the instructions [here](http://www.github.com/WellDone/MoMo-Firmware/wiki/Development-Dependencies).

### Looking Around
```shell
> ls
config  doc  momo_modules  pcb  README.md  tools
```

A brief overview of what is what:
* config - reference information about pcb layouts and build constants.  Templates for module skeleton code is stored here as well
* doc - assorted datasheets and reference information.  Not terribly well organized currently
* momo_modules - all module firmware is stored under these directories.  momo_modules/shared contains shared library code.  Other directories correspond to a single firmware image each.
* pcb - all circuit board
* tools - all of the support infrastructure is stored in the tools directory.  You should add tools/bin to your PATH for easy access to the support tools.  Most of the build system is implemented as a python package pymomo which lives in tools

### Step 3 - Required Configuration
This is only required if you want to use pcbtool to automate processing of circuit board designs.  You must edit the file config/settings.local.json to contain the path to your local copy of EAGLE.

```shell
> cat config/settings.local.json 
{
	"external_tools":
	{
		"eagle": "<INSERT PATH TO EAGLE HERE>",
		"gpsim": "/opt/pic/bin/gpsim"
	}
}
```

In order to use the unit testing infrastructure for pic12 code, you must also configure the gpsim path but this is not yet supported since we require a modified version of gpsim (to fix many bugs in the main codebase that we hit).  Our internal gpsim version will be released soon and then unit testing will be available for everyone.

### Checking that Everything Works
Assuming that you added tools/bin to your PATH variable, you can use the modtool program to talk to a connected MoMo unit.  Plug in your MoMo FSU into a USB port and plug the other side into a MoMo unit.  Power the MoMo unit and you should see two green lights illuminate.  Usually modtool will be able to guess which port your MoMo is plugged into, if not you will need to know the device or com port that corresponds to the MoMo FSU.  

On linux it is probably:
```shell
/dev/ttyUSB0
```

On Mac OS X is is probably:
```shell
/dev/tty.usbserial.SOMETHING
```

On Windows is is probably COM2 or COM3 depending on how many other serial ports you have.  If you are using cygwin (which we don't recommend), then the serial port will show up probably as something like:
```shell
/dev/ttyS2
```

**Note:**  On OS X Mavericks, apple broke FTDI USB-Serial adapter support so you need to implement the workaround described here to install a working driver: http://forum.arduino.cc/index.php?topic=198539.0

If you need a driver for the MoMo FSU, it uses the FTDI 230X chip which has drivers here:
http://www.ftdichip.com/FTDrivers.htm

In what follows, _PORT_ will refer to the device or COM port as listed above that corresponds to your computer.  Try to access the MoMo and list all of its attached modules to make sure everything is working:
```shell
modtool list
0: pv_mod
1: Whatever
2: Something else
```

If the command finishes without error, you are completely set up.  If it throws an exception then it was not able to guess your COM port correctly and you'll have to specify it explicitly, i.e.:
```shell
modtool list -p PORT
0: pv_mod
1: Whatever
2: Something else
```

### Step 4 - Read up on how to use all of the tools
There is documentation for all of the support tools that help you use MoMo.  Read about them:
* [[modtool|modtool]]

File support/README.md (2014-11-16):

##Support Files
These files are support for external tools that may require modification in order to work with MoMo.  Currently the only such tool is gpsim, which requires a patch in order to correctly simulate Enhanced Midrange PIC processors.  In order to apply the patch you need to download gpsim from svn, apply the patch.

This document assumes that you are checking out gpsim into the parent directory containing MoMo-Firmware.  If this is not the case you will need to specify
the path to gpsim_16lf1847_support.patch based on your system.

```shell
> mkdir gpsim
> cd gpsim
> svn checkout svn://svn.code.sf.net/p/gpsim/code/trunk -r 2281 .
<Lots of text>
> patch -p0 -i ../MoMo-Firmware/support/gpsim_16lf1847_support.patch
patching file src/14bit-hexdecode.cc
patching file src/14bit-instructions.h
patching file src/Makefile.am
patching file src/makefile.mingw
patching file src/p16f1847.cc
patching file src/p16f1847.h
patching file src/p1xf1xxx.cc
patching file src/p1xf1xxx.h
patching file src/pic-instructions.cc
patching file src/pic-processor.cc
patching file src/pic-processor.h
```

Now you need to follow the [instructions](http://gpsim.sourceforge.net/gpsim_svn.html) to build and install gpsim.  For reference, the current required commands are:

```shell
> libtoolize --force
> aclocal
> autoheader
> automake --force-missing --add-missing
> autoconf
> ./configure
> make
> sudo make install
```

Make sure you install gpsim into your $PATH correctly and you should be able to build pic12 unit tests.  As a test, navigate to the pic12_executive directory
and make sure you can build the tests:
```shell
> cd MoMo-Firmware/momo_modules/pic12_executive
> momo build -c
> momo build test
```

You need to have the pro mode compiler currently to build the pic12_executive.

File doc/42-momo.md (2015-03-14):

## momo (the command line tool)

```momo``` is a powerful command line tool that can be used to explore the pymomo python API and to interact with the momo hardware.  It is the most basic way to interact with the MoMo ecosystem.  The ```momo``` tool is based on the concept of hierarchical contexts which have one or more methods that can be called in that context.  This section details how to understand and use the ```momo``` tool at a basic level as well as advanced customization and usage at the end of the section.

### Quick Introduction
The python API that is used to interact with the momo hardware consists of a number of classes, some of which are proxy objects for hardware devices and others represent types and data on the computer.  As an example, consider interacting with a MoMo controller module.  There is a python class ```MIBController``` that represents the controller connected to the computer and internally converts all method calls on that object into RPC calls that are sent to the controller hardware and the response is presented as the result of the function call.  This lets you control the MoMo hardware as if you were just programming with a standard python object.  

The momo tool has two key concepts: contexts and methods.  A context is a container that has a number of methods.  So ```MIBController``` is a context.  Each context has a number of methods that it can execute.  When you run the momo tool, it lets you call any context's method from the command line.  Internally all of the arguments you pass on the command line are converted to python objects and the method (which is just a regular python method) is called with the result printed for you.  This provides an easy way to interact with any object in the pymomo API without needing to write a python script.  You can just write commands with the momo tool and have them automatically converted into python calls.

When you're ready to write your own scripts, there is a direct 1:1 mapping between ```momo``` commands and python statements, so it's trivial to explore the MoMo ecosystem using the ```momo``` tool and then write more advanced scripts in python once you get the hang of everything.  The system that makes this possible is ```typedargs```, a python framework for annotating functions and classes with additional information that lets the momo tool convert command line strings into typed python objects and validate that the data entered makes sense.

If you have a MoMo controller plugged into your computer, we can do an example to demonstrate.

```
> momo
(root) 
```

Upon executing the momo command with no arguments you're dropped into the root context and momo creates a REPL (Read-Eval-Print Loop) for you to work in.  You can explore what commands are available using tab completion.  Pressing tab twice shows all of the available commands in this context (powered by GNU readline so it works the same as in the normal shell).

```
(root) <TAB><TAB>
ControllerBlock  Simulator        build            help             quit       
HexFile          back             controller       import_types     
(root) 
```

These are the commands that are available to you at the root level.  To see more details, use the builtin ```help``` command:
```
(root) help
root

Defined Functions:
 - Simulator(string type)
   Generic interface for simulating embedded microprocessors.

 - import_types(path package, string module=None)
   Add externally defined types from a python package or module

 - controller(string serial='')
   Given serial port descriptor, create all of the necessary

 - build(args)
   Invoke the scons build system from the current directory, exactly as if 

 - ControllerBlock(path source)
   The metadata block in a pic24 controller firmware image.  This includes

 - HexFile(path source, integer wordsize, integer filewords, integer skip=1, integer cutoff=65535)
   A generalized container object for representing sparse memory views like those

Builtin Functions
 - quit: quit the momo shell
 - help [function]: print help information about the current context or a function
 - back: replace the current context with its parent
```

```help``` without any arguments prints short documentation on all of the available methods in this context.  To learn more about any particular method, use ```help <method>```.

```
(root) help controller

Given serial port descriptor, create all of the necessary
object to get a controller proxy module 

Arguments:
 - serial (string): the serial port to use
```

Notice how you see a docstring for the method drawn directly from the pymomo package as well as descriptions and types for any arguments that it accepts.

Now lets start interacting with the controller board.

```
(root) controller
(MIBController) help

MIBController
A python proxy object for interacting with the MoMo controller board.

Defined Functions:
 - reset(sync=True)
   Instruct the controller to reset itself.

 - current_time()
   Get the current time according to the controller's RTCC

 - sync_time()
   Set the time on the momo controller to the current system time.

 - read_log()
   Read the MoMo system log

 - enumerate_modules()
   Get list of all attached modules and describe them all

 - build_report()

 - clear_log()
   Clear the MoMo system log.

 - get_module(string name=None, integer address=None, force=False)
   Given a module name or a fixed address, return a proxy object

 - perf_counter(integer counter)

 - count_modules()
   Count the number of attached devices to this controller

 - get_report()

 - factory_reset()
   Instruct the controller to reset all internal state to "factory defaults."  Use with caution.

 - set_time(year, month, day, hours, minutes, seconds, weekday=0)
   Set the current time of the controller's RTCC

 - read_ram(integer address, string type=None, integer size=0)
   Read bytes from the controller ram starting at the specified address.  If a 

Builtin Functions
 - quit: quit the momo shell
 - help [function]: print help information about the current context or a function
 - back: replace the current context with its parent
```

Notice how the context changed from root to MIBController.  From now on any method we execute will be one defined in the MIBController class.  If you're done with a context and want to go back, use the builtin function ```back``` to destroy the current context and go back to its parent.  Technically, the list of contexts you've visited forms a stack so you can always pop the top context off and go back to the one before it using the ```back``` command.  

If you type back from the root context, ```momo``` will exit since there's no context to go back to.  Otherwise you can quit by typing ```quit``` in any context since its a builtin function that's always available like ```back``` and ```help```.

The core concept of ```momo``` is that if you know the python method you immediately know how to call it in ```momo``` and if you call a method using the ```momo``` tool you also know how to call it in python since the two are always linked.  The purpose of the ```momo``` tool is to provide an easy way to interact with the pymomo API without having to write python scripts for everything.

### Using momo without dropping into a shell

If you just want to type a quick command, you can do so without first creating a shell by entering the command into the initial command line used to invoke ```momo```.  For example, to reset a connected controller board just use:

```
> momo controller reset
```

Internally, momo parses the command line piece by piece so first it enters the controller context and then calls the reset method.  If the last method invoked does not create another context, the momo tool terminates since this is likely what you wanted.  If on the other hand, the last method does create a context then momo drops you into a shell in that context.  This lets you speed up access to contexts that you want to interact with for some time but require several commands to setup.  For example:

```
> momo controller
(MIBController) 
```

You can chain as many methods together as you like, so if you want to pull a system log from a MoMo controller and display it you could do:
```
> momo controller read_log display 
PERFORMANCE (2000-01-31 16:30:20) Periodic log of how often the microprocessor is asleep
 - Total Ticks: 23110
 - Sleeping Ticks: 22370
 - Number of prevented sleeps: 0
 - Tasks: 0x2356
CRITICAL (2000-01-31 16:30:20) The MoMo controller received a reset RPC and is resetting
CRITICAL (2000-01-31 16:30:20) The MoMo controller has been reset
CRITICAL (2000-01-31 16:30:20) The MoMo controller has been initialized
CRITICAL (2000-01-31 17:23:32) The MoMo controller received a reset RPC and is resetting
CRITICAL (2000-01-31 17:23:33) The MoMo controller has been reset
CRITICAL (2000-01-31 17:23:33) The MoMo controller has been initialized
PERFORMANCE (2000-01-31 17:23:40) Periodic log of how often the microprocessor is asleep
 - Total Ticks: 27576
 - Sleeping Ticks: 26890
 - Number of prevented sleeps: 0
 - Tasks: 0x2356
```

```momo controller read_log``` pulls the system log from the MoMo controller board and creates a SystemLog context with the information it receives.  This context supports the display method to show its contents, which is then invoked.  

### Running Commands on Startup

You'll likely find that you want to set up the momo tool to always initialize certain contexts everytime you create them.  For example, the SystemLog context requires commands adding LogDefinition files so that it knows how to parse the data that it's getting back from the MoMo controller.  The actual command that was executed in the last example was:

```shell
> momo controller read_log add_ldf mainboard/src/log_definitions.ldf add_ldf shared/pic24/src/log_definitions.ldf display
```

However, this is tiresome to write.  So you can create a configuration file that contains momo commands that are run whenever a certain context is created.  The format of the file is straightforward:

```
> cat ~/.config/momo_config.txt
[root]
import_types /home/timburke/Projects/MoMo-Firmware/momo_modules/shared/pic24/python/firmware_types

[MIBController.SystemLog]
add_ldf /home/timburke/Projects/MoMo-Firmware/momo_modules/mainboard/src/log_definitions.ldf
add_ldf /home/timburke/Projects/MoMo-Firmware/momo_modules/shared/pic24/src/log_definitions.ldf
```

The file should be called momo_config.txt and stored under the .config directory in your home folder on unix and in %APPDATA% on windows.  To Find where the config file should be stored on your system just run:

```
> momo --rcfile
/Users/timburke/Library/Preferences/momo_config.txt
```

The example shows the directory location on a Mac OS X system.

On all systems, the format of the momo_config file is the same.  It consists of a list of context patterns in brackets followed by initialization commands.  Whenever a context matching the pattern is created, the initialization commands are run.  A context pattern can be either a single context name like root for the root context or a hierarchy of contexts separated by dots.  For example, above we want to run a few add_ldf commands everytime a SystemLog is created by a MIBController.  If the SystemLog is instead created by another context, we don't want to modify it.

Adding commands under the root context will cause them to always be run when you invokve the ```momo``` tool.

### Adding Additional Types
If you create your own MoMo hardware modules or get them from other people, there will likely be additional proxy objects and types that will be useful for interacting with those modules but not contained in the core pymomo package.  The root context of ```momo``` has a method ```import_types``` that imports arbitrary types and makes them available for use in the momo tool.  It's usage is beyond the scope of this section though and will be detailed elsewhere.

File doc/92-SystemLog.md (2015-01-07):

# Understanding and Using the MoMo System Log
Each MoMo controller board has a nonvolatile system log that is used to log debug and error information as well as (in the future) for running hardware tests.  The log is stored in the external flash memory on the controller board as a circular buffer so, if it fills up, the oldest entry will be overwritten.  This document details how the system log is structured as well as how to interact with it and use it programmatically.

In order to be fast and general, log message strings are not embedded into the system log, instead a 32-bit hash is generated as a unique ID for each log message and that id is stored in the log.  Parsing the log back to string messages rather than message IDs requires having access to the Log Definition File that was used to compile the firmware code that emitted the log message.

## System Log Format
The system log is composed of a series of typed entries (RawEntry) of a fixed size (currently 16 bytes).  A log entry starts with a RawEntry containing the timestamp (accurate to the second) of the logging message as well as a 32-bit id number that corresponds with the message being logged.  It is followed by zero or more RawEntries that correspond with parameters that are associated with the log entry.  If parameters are too big to fit in a single RawEntry, they are automatically split across as many RawEntries as necessary.  Integer (16-bit) parameters are packed into a single RawEntry to save space when possible (7 per entry since 1 byte is taken up with entry type information).

### Parameter Types
Currently the supported parameter types are integer, boolean, string and blob.  Blob simply indicates that the data should be interpreted an an opaque array.  The corresponding log definition for this entry can specify how to interpret the blob and display its logical internal structure in a useful way.

## Using the System Log Programmatically (controller)
From controller code, which has direct access to the system log without making an RPC, you can use the following logging macros to log information.  First, make sure you include the appropriate headers:

```c
#include "system_log.h"
#include "log_definitions.h"
```

```log_definitions.h``` is a header file generated during the compilation process that contains a map between log statements and the 32-bit hash ids that are actually stored in the system log.  You should not edit it directly but rather edit the log_definitions.ldf file that is used to generate it.  

To log a message simply use:

```c
LOG_CRITICAL(message_id);
```

There is a also a corresponding ```LOG_DEBUG(message_id)``` macro that can be used.  If you wish to attach parameters to the log statement you can do so by following the initial LOG_**STREAM** statement with an arbitrary number of parameter log statements, for example:

```c
LOG_INT(10);
LOG_POINTER(ptr);
LOG_STRING("Hello world.");
LOG_ARRAY(array, length);
LOG_BOOL(true);
```

When the system log is read, parameter log statements are implicitly associated with the last message_id.

## Using the System Log Programmatically (other modules)
Remote logging from other modules is not yet supported by the system log though support is planned for this feature.

## Creating New Log Entry Types
Every log entry in the system must correspond with a log definition in a Log Definition (.ldf) file.  The format of this file is straightforward and just lists the name of the log statement, the message that corresponds with it, and any parameters that it expects.  The format is:

```
LogStatementName
"quoted string message"

- "Parameter name" [list of] type[, format format_name]
<zero or more parameter statements> 
```

An example with and without parameters is:

```
PowerOnNotice
"The MoMo controller has reset due to a power-cycle event"

DeviceResetNotice
"The MoMo controller has been reset"
- "Welcome mat" as string
- "Welcome number" as integer, format hex
```

The type should correspond to a known type in the typedargs type system and is used to interpret the binary data logged with the entry.  If format is 
specified, it should correspond to a defined formatting routine for the given type.  If no format is specified, then the default formatter for the type
is used. 

You can also define a log statement to contain a list of parameters with variable length but common type.  For example, to log the list of all tasks in the controller taskloop structure you could define a log entry as follows:

```
TaskLoopFullError
"The taskloop was completely full and a new task was added"

- "Tasks" as list of fw_task
```

The special syntax ```list of <type>``` defines this entry to consume all remaining logged parameters.  You can have at most one list per log entry and it must be the last parameter.  If you create an LDF file violating this rule, the build system will throw an error to let you know.

###Important Notes

- The 32-bit message id is formed from the low 32 bits of the MD5 hash of the LogStatementName, so if you change the LogStatementName, it will no longer hash to the same value and hence the system log reading functions will not be able to match it with the hash value stored in the system log.  *You should avoid* changing the name of existing log entries and instead just create new log entries.
- There is a very small, though nonzero probability that two Log Statement Definitions collide to the same hash value.  If this happens, the build system will throw an exception and you will have to modify the name of one of the definition names in order to fix the collision.  With 4 billion choices, this should not be too much of a problem.

## Reading the System Log
Using the momo tool is the easiest way to read the system log.  The most basic option would be to connect the momo to the computer and then use:

```shell
> momo controller read_log display
CRITICAL (2000-01-31 16:02:14) 0xF520EAFE
CRITICAL (2000-01-31 16:02:14) 0x67F94DC9
 - Hello world.
 - 10
CRITICAL (2000-01-31 16:02:14) 0x17CE2635
```

You can see each log enty with its stream as well as any parameters with which it was logged.  The log statement is displayed as a hex hash value because you haven't added any ldf files with which to interpet the log.  You can do so interactively by dropping into a momo shell:

```shell
> pwd
/home/timburke/Projects/MoMo-Firmware/momo_modules/mainboard
> momo controller read_log
(SystemLog) display 
CRITICAL (2000-01-31 16:02:14) 0xF520EAFE
CRITICAL (2000-01-31 16:02:14) 0x67F94DC9
 - Hello world.
 - 10
CRITICAL (2000-01-31 16:02:14) 0x17CE2635
(SystemLog) add_ldf src/log_definitions.ldf
(SystemLog) display
CRITICAL (2000-01-31 16:02:14) The MoMo controller received a reset RPC and is resetting
CRITICAL (2000-01-31 16:02:14) The MoMo controller has been reset
 - Welcome mat: Hello world.
 - Welcome number: 0xA
CRITICAL (2000-01-31 16:02:14) The MoMo controller has been initialized
```

Each module that contains logging statements should include a file named log_definitions.ldf in the src directory.  This is the file that should be included using the add_ldf directive. Note how the ldf file both lists the appropriate message to use with the log statement as well as how to interpret and display the parameters.  If you want to do this in one line you can use:

```shell
> momo controller read_log add_ldf src/log_definitions.ldf display
CRITICAL (2000-01-31 16:02:14) The MoMo controller received a reset RPC and is resetting
CRITICAL (2000-01-31 16:02:14) The MoMo controller has been reset
 - Welcome mat: Hello world.
 - Welcome number: 0xA
CRITICAL (2000-01-31 16:02:14) The MoMo controller has been initialized
```

You can add as many ldf files as you like in order to interpret all of the logging statements in the system log.  By default, if there is no log definition available, momo just diplays the raw parameters and the hash of the message id.

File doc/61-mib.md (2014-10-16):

# Module Interconnect Bus (MIB)
The Module Interconnect Bus is a shared remote procedure call type communication bus allowing for communication between different modules in the MoMo ecosystem. 

##Physical Specification
The MIB is an i2c bus.  Each module PIC will be connected via SCL and SDA lines that are open drain with pull up resistors on the controller board only.  The i2c bus will run at 100 KHz.  

##Message Structure
The i2c bus has a master-slave format.  The master controls SCL and sets the direction of data transfer.  It can either send or receive data from the slave.  Each complete message in the MIB protocol will correspond logically to a remote procedure call (RPC) where the master is executing a procedure on the slave and getting the return result.  This is summarized in Figure 1.


Figure 1

The master begins the transaction with the slave by sending an i2c start condition with the slaves address and write indicated.  It sends a packet specifying the feature and command, which uniquely determine the function the slave should execute.   At this point the slave searches for a handler function to handle that command and clock stretches until it has found one or determined that it does not support the command.

The master then sends another packet with the typed parameter list for the command.  The slave receives these and stores them in a buffer specified by the command handler found for the command.  The master then sends a repeated start with read indicated to read the return value for the command.  Upon receipt of this, the slave begins executing the command and clock stretches until it has finished, at which point the master reads at least one and up to two packets specifying the status of the executed command and its return value if there is one.

The master then sends a write packet with at least 1 byte to reset the slave according to the bus Slave Reset Protocol.

The master then sends an I2C stop condition to terminate the communication and both master and slave return to an idle state to await the next communication. 

##Packet Structure
All messages that go onto the wire are composed of packets.  A packet is a series of bytes beginning with an address and ending with a checksum.   It has the following format.  
```
Start or Repeated Start
Address + RW
Data byte 1
…
Data byte n
Checksum
```

###Checksum
The packet checksum is calculated as the 2’s complement of the sum of the data bytes in the packet, not including the address ignoring overflow.  The sum is calculated by using an unsigned 8 bit accumulator value initialized to 0 at the beginning of the packet transmission.  As each byte is transmitted over the wire it is added to the accumulator, ignoring overflow.  After the last data byte is transmitted, the accumulator is negated and 1 is added to it to form the two’s complement, which is then transmitted as the final byte of the packet.  

So a packet with N data bytes will transmit N+2 bytes (address + N data bytes + checksum).  

###Acknowledge Bit
The i2c protocol requires that an acknowledge (ACK) or not acknowledge (NACK) to be transmitted after each byte is transmitted on the wire.  What this bit means depends on the direction of the message.

####Master Writing to Slave
When the master writes 8 bits to a slave, it generates a 9th clock pulse for the slave to send it an acknowledge bit.  The slave should always send ACK.  ACK means that it received 8 bits, not that it knew what to do with them or that they were the bits it was expecting.  This is because the pic24 hardware i2c logic automatically acknowledges received bytes and only sends NACK if the receive buffer is full.  

####Master Reading from Slave
When the master reads from the slave, it generates 8 clock pulses to read 8 bits from the slave and then generates a 9th clock pulse to send an ACK/NACK bit to the slave.  It is very important that the master ACK every data byte from the slave and NACK the checksum byte.  This is because ACK for master reads means that the slave should continue sending bytes.  NACK means that the slave should stop sending bytes.  If the master does not NACK the last byte in the packet (the checksum byte always), the slave will think it should transmit another bit and will in some cases keep pulling SDA low waiting for a clock pulse.  This does not allow the master to control SDA and send a stop condition, causing a bus fault. 

##Protocol Layers
The MIB protocol can be thought of as composed of distinct layers: the i2c physical layer, the packet layer and the RPC layer.  The i2c physical layer controls bus access, and sends or receives bytes from the wire.  The packet layer sends opaque data packets + checksums and verifies the checksum.  The RPC layer composes packets and defines the overall flow of the transaction.

##Parameter Data Structure and Type
MIB supports the following logical parameter types: integer (8 or 16 bit), string and opaque buffer.  On the wire, there are only two wire parameter types (integer and opaque buffer).  The 4 logical parameter types are encoded into these two types in the manner described below.  

##Automatic Recovery from Transient Bus Errors
Every packet in the MIB protocol has a checksum so that the recipient can be sure it has been received without error.  However, this is not an error correcting code, so the recipient must ask the sender to resend the data until it is received correctly.  There are 4 points in the MIB protocol where data integrity is checked:
* When a command is sent (master->slave)
* When all parameters are sent (master->slave)
* When the command status is read (slave->master)
* When the return value is read (slave->master)

Note that the slave does not execute the command handler until it has verified that the command and parameters were received correctly so, if there is a checksum error from master->slave in either the command or the parameters, the master will send a Slave Reset and then begin the command again.  Because the RPC layer stores buffers the command, slave address and all parameters internally, it can retry the command without requiring the user code to do anything.  Also, since it is guaranteed that the command handler on the slave side was not run if the checksum failed, the master is free to reinciate the RPC without worrying that the command may not be idempotent.  

If the checksum fails from slave->master, the master will keep sending read indications in pairs of 2 and the slave will keep sending the same status and return value until the master stops sending reads, indicating that the checksum was correct.  Since the slave RPC layer buffers the return value from the command handler it ran as well as the return status, it can resend them freely without needing to consult usercode.  

Thus, once a MIB RPC has finished, we can be guaranteed that it completed correctly without a transient bus error.  

###Slave Return Value Transmission
Slaves always respond to read requests from the master with data according to the following protocol.  If the slave has received an even number of reads, it sends its return status.  If it has received an odd number of reads, then it sends its return value.  This allows the master to repeatedly query the return status and value until they are correctly received.  If the slave is asked to send a return value and it did not execute a command_handler that returned a value, then it will send 1 garbage byte which the master must ignore.  

```
Slave Read 1 - send return status (2 bytes)
Slave Read 2 - send return value or garbage (at least 1 byte)
...
Slave Read 2N+1 - send return status (2 bytes)
Slave Read 2N+2 - send return value or garbage (at least 1 byte)
```

##Slave Reset Procedure
A significant issue with the i2c protocol is that there is no resynchronizaton procedure.  If a slave misses one clock, it will be 1 bit out of sync and misinterpret all subsequent data.  An obvious solution is to have the slave key in on the i2c stop condition and reset itself to a known state when a stop is received.  However, the PIC24 and probable PIC12 do not interrupt when a stop is received :(.  As a workaround we define a bus-specific reset procedure for returning a slave to known state independent of the course of events that screwed it up.  

The reset procedure is based on the observation that in the normal MIB transaction flow, the master never sends a write after a read.  It writes a command, writes a parameter and then reads the return status and return value.  So, the slave can be sure that if it receives a write after having received a read in the same transaction that this is an exception and reset itself.  This is implemented by having the slave keep an internal counter of how many reads it has received in the transaction (num_reads).  If it receives a write and num_reads > 0, then it resets itself back to idle.  

Note that the master does not need to know how the slave got screwed up in order to reset it.  It can just send one read followed by one write and be sure that the slave will then be idle and ready to receive a command.

###Reset Procedure
```
Slave state unknown: num_reads = X >= 0
Master Sends Read (1 byte): num_reads = X+1 > 0
Master Sends Write (1 byte)
Slave resets itself 
```

##Master Logic Flowchart
Figure 2 below shows the complete MIB Master state machine including all error processing.  This shows error processing paths as well.


Figure 2

##MIB FAQ
This section is to document why certain decisions were made.  This is not to say that they are the best option and should not be changed or revisited, but rather that we should understand the considerations that drove their choice so that a potential replacement doesn't fall afoul of the same problem.

###Why are the parameters all sent as a single packet?
This is to allow for easy command resending.  Currently the parameters are all composed into a packet in the mib_buffer and sent.  We know that they all fit into the mib_buffer since they are sent as a single packet which is limited in size to the size of the mib_buffer.  If there is a problem sending the parameters (arbitration lost or checksum error), we still have them all in the mib_buffer so we can resend them without needing usercode to provide them again.  This means the usercode can assume that the process always succeeds.

###Why is there a return status and a return value?
The return value is a typed parameter defined by the specific command being called, which the MIB layer knows nothing about.  However there needs to also be a way to indicate whether the command was successfully called or to signal that the parameters need to be resent, for example.  The return status serves this purpose.  Also, the slave needs to tell the master how many bytes are in in the return value (which can be a buffer so its unknown apriori).  So the return status sends a length to tell the master how many bytes to read in for the return value.  This also allows for void return values (the return status has a length of 0).

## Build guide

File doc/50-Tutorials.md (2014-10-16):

# Tutorials
Several step-by-step guides to get you started.

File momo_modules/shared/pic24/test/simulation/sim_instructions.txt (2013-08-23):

LD pic24super             
LC build/test/TestBuild.out
IO NULL build/test/out.txt
RP
E

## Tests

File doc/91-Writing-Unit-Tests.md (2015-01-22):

# Writing Unit Tests
The MoMo build system supports unit testing of firmware code in order to ensure robust functionality.
There are two different systems in place for testing 8-bit and 16-bit code since the architectures are
very different.  The structure of the unit tests is the same but the available functionality is different
as will be discussed below.  8-bit unit tests are run on the [GNU PIC Simulator](http://gpsim.sourceforge.net).  16-bit
unit test are run on Microchip's free but proprietary simulator sim30.  We use a customized version of gpsim until 
upstream supports all of the features we need.  Read the Contributing section for instructions on how to install and
patch an appropriate version of gpsim.

## Unit Test Introduction
Unit tests should consist of a single file each (with possible support files that vary based on the unit test type)
and should be stored in the test subdirectory of the module to which they pertain.  In the examples in this document
we will consider the 8-bit module pic12_executive.  You can see the unit tests defined for this module:

```shell
$ cd momo_modules/pic12_executive
$ ls test   
support_bus_master.cmd          test_boot_address.as        test_find_handler.as
support_find_handler_mib.as     test_bus_checkparam.as      test_flash_write.as
support_i2c_slave_16lf1847.cmd  test_bus_master.as          test_i2c_slave.as
support_i2c_slave.cmd           test_bus_returnstatus.as    test_i2c_utils.as
support_i2c_slave_receive.cmd   test_bus_slave_16lf1847.as  test_no_appmodule.as
support_no_appmodule.as         test_bus_slave.as
test_basic.as                   test_call_handler.as
```

Each file with a name that begins with 'test_' defines a unit test and all other files are supporting files that
are included in their corresponding unit tests.

## Defining a Unit Test
All unit tests need to contain a header the describes the unit test.

```shell
$ head -n 4 test/test_call_handler.as
;Name: test_call_handler
;Targets: all
;Type: executive
;Description: Test to ensure that the find_handler function works 
```

The header must start with either a ';' for assembly test files on 8-bit processors or a '//' in C test files and it
must be at the top of the file.  Only whitespace is allowed before the header starts.  The header consists of a list
of Name: Value pairs, called test attributes, some of which are required and others are optional.

### Required Test Attributes
All tests must define the attributes Name, Targets, Type and Description as described below:

- *Name* The name of the test.  This must not contain any whitespace and should be unique among all of the tests for a given module

- *Targets* If this test should only be compiled for a subset of the target architectures that this module targets, you need to list that 
subset here as a comma separated list.  For example

- *Type* The type of unit test that this is.  There are various options that are valid only for 8-bit and others only for 16-bit.

```
Targets:16lf1823,16lf1847
```

This would only compile the test for the 16lf1823 and 16lf1847 targets of the module.  If a test should be compiled for each target, specify

```
Targets: all
``` 
- *Description* A description of what the test does.  Description is allowed to extend onto multiple lines if it is the last attribute defined
for the test.  It is recommended that Description be the last attribute in the attribute list.

### Optional Test Attributes (8-bit)
Some attributes are used to add additional functionality to tests.  The attributes supported on 8-bit unit tests are:

- *Additional* takes a comma separated list of additional filenames that are added to the test. Depending on the file extension the files are 
processed differently.  If a .as file is listed it is compiled along with the main test file and may contain additional code or anything else
that can be compiled in a .as file.  If a .cmd file is specified then it is used to create a custom command script to drive gpsim.  This lets
unit tests define stimuli for the test to respond to, for example.  See support_i2c_slave.cmd for an example.  Since the cmd file is appended to 
the normal (autogenerated) test script, it must end with the run command so that the test is actually executed.

- *Checkpoints* takes a comma separated list of tokens in the form symbol=value, where value is an 8-bit integer in decimal, hex or binary.  
Checkpoints define a sequence of actions that must complete in order for the test to be considered successful.  For an example see test_basic.as
in pic12_executive/test.  Checkpoints are discussed in more detail in the Using Checkpoints section.

- *Patch* takes a comma separated list of taken in the form old_symbol=new_symbol and patches the hex file under test so that the first 3 words of
the function specified by old_symbol are replaced with an unconditional goto to new_symbol, which is the replacement function.  This lets tests
hook other functions that they want to either mock or checkpoint.

### Optional Test Attributes (16-bit)
Fill this in as we write more 16-bit unit tests and build-out more features in the framework

## How 8-bit Unit Tests Work
All 8-bit modules are divided into two components: the executive and the application.  The executive takes the first ~1K of ROM of the processor
and the application takes the rest of the ROM.  Since these are small chips and the application code might be tightly coupled, it makes the most
sense to test it as a unit.  So, unit tests for applications work by replacing the executive portion of the firmware with the unit testing code
and keeping the entire application code as it would be in the real module.  Executive tests work in a similar way by replacing the application code
with the unit testing script.  This is done automatically by the build system.  

There are three types of 8-bit unit tests that must be specified in the Type attribute: executive, executive_integration and application.  Executive unit tests can only be 
defined for the pic12_executive.  All other application modules must define all of their tests as application tests.  By default, no module code is run before jumping directly to the unit test code except when executive_integration testing is specified.  ```executive_integration``` tests run through the complete executive startup code and run the unit test code as an application module.  This lets you test things that require a fully initialized mib12_executive.

### An Example Unit Test
FILL In this section

### Including Different Support Files on Each Architecture
Sometimes the same unit test code will run on multiple architectures, so you would like it to run on multiple architectures, but those architectures require different support files.  For example, if you want to test whether a certain pin triggers an interrupt, the test code is the same: did the interrupt get triggers, but what if the pin is in a different location on the different architectures.  The unit testing build code handles this in the following way.  When you specify an additional file like a .cmd file to pass commands to gpsim or a .as file to include in your unit test code, the build system internally looks for that file name appended with the architecture currently being targeted and if that file is found, will use it instead of a generic version.  

For example, say that you're targeting the architectures ```12lf1822/v1``` and ```12lf1822/v2```.  In your unit test you have an additional file include statement like the following. 

```
Additional: support_pinlocation.cmd
```

When building for the v2 architeccture, the build system parses your architecture string into a prefix list:

```
["12lf1822", "v2"]
["12lf1822"]
[""]
```

It then splits the support file prefix off and adds in the architecture prefixes, in order until it finds a file that exists.  So it looks for:

```
support_pinlocation_12lf1822_v2.cmd
support_pinlocation_12lf1822.cmd
support_pinlocation.cmd
```

Once it finds a match it stops.  If no match is found, it throws a BuildError.  On the v1 architecture, the build system looks for 
```support_pinlocation_12lf1822_v1.cmd``` first, so you can just specify two different support files and the build system will pull them in automatically for the right architecture without needing to create a separate unit test code file.

### Using Checkpoints Effectively
FILL In this section

## How 16-bit Unit Tests Work

## Miscellaneous Information

### How Unit Tests are Discovered by the Build System
Inside the SConstruct file that builds each module are commands to search for a test subdirectory and create unit tests from each file in that directory
whose name begins with test_.  Adding a unit test is as simple as defining a new test_*.{c,as} file in the test directory for the module you would like
to test.

## How To Run Unit Tests
Each module has a default target alias called test that builds all of the unit tests for that module

```shell
$ momo build test
```

## Seeing Unit Test Output
Unit tests are run on the simulator and produce a log of their activities.  This log is stored in build/test/output/logs for each module.  This log is
then parsed by the build system to determine if the test passed succesfully and the result is written to a '.status' file containing either the world
PASSED or FAILED.  Then the build system examines the status files for all of the tests for each target architecture and creates a summary file in
build/test/output called results.txt that summarizes the results.  For the pic12_executive module we have

```shell
$ cat build/test/output/results.txt
Test Summary

## Target 16lf1823_exec ##
9/9 tests passed (100% pass rate)

## Target 16lf1847_exec ##
10/10 tests passed (100% pass rate)

## Target 12lf1822_exec ##
12/12 tests passed (100% pass rate)
```

Test results are broken down per target and the logs for any tests that fail can be inspected in build/test/output/logs.  The status and log files are
named according to the test name and architecture: test_foobar@random_architecture.{log,status}.

The test results are also shown at the end of momo build test:

```shell
$ momo build test
<lots of text>
Test Summary

## Target 16lf1823_exec ##
9/9 tests passed (100% pass rate)

## Target 16lf1847_exec ##
10/10 tests passed (100% pass rate)

## Target 12lf1822_exec ##
12/12 tests passed (100% pass rate)
scons: done building targets.
```

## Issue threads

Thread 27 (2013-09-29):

Sensor-agnostic, communication-module-limited report formatting

amcgee, 2013-09-29:
Reports should be condensed and/or streamed to the comm module based on the limits of the communication format, and shouldn't need to be aware of which sensor is attached to the device.  This reporting format will also need to take into account the possibility that multiple sensors are reporting through a single comm stream, as well as that different users might have different verbosity/bandwidth-conservation tradeoff requirements.

amcgee, 2015-03-14:
Moving bandwidth limitation to a new issue

Closed 2015-03-14.

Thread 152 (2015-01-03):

Get Python Type System to Version 1.0

timburke, 2015-01-03:
pymomo now relies fairly heavily on a typing system for some of its functionality.  The type system supports the following features:

- Annotate function arguments with a type so that the can be validated and converted from strings
- Conversion routines for each type from string
- Validation routines for each type that are particular to that type
- Formatting and printing routines for displaying the type in a nice fashion

This functionality is used currently in the following places:

- momo tool to convert command lines into python function calls
- syslog to display the typed parameters associated with each system log entry
- debug variable reading to display typed variables from the controller during operation

The type system works well but several outstanding features and refactoring  would be useful before considering it stable.  The isue tracks progress on these features.

- [ ] Add return value typing on annotated functions and use the formatting information from the type to print it in the momo tool rather than the current custom printer for each function that doesn't want the default str() conversion printing behavior
- [ ] Add ability to inject types from other python modules dynamically so that users can define their own types and use them.
- [ ] Add config file to momo tool that lets you set up the environment with your custom types and other config routines to make calls to momo less verbose
- [ ] Write more general unit tests using pyunit and include
- [ ] Split typedargs into a separate reporsitory and installable python package (momobase?) along with exceptions.

amcgee, 2015-01-04:
Agree on most of these, couple questions:

1. Is a config file the right way to go?  Doesn't that make custom extensions more difficult?
2. Should typedargs and exceptions be a separated from pymomo (2 new repos) or should all of pymomo be together in a separate repo?

timburke, 2015-01-04:
Not sure on either.  For 2, we can keep it all together in a separate repository, my concern would be if it gets really big but I don't really have a preference on this.  Only thing for splitting out typedargs is that it doesn't rely on anything else in pymomo so it could be a standalone package that other people could use.  But I don't see a need to do that anytime soon so we could keep together.

For 1, I'm not set on a config file but here's the use case that I'm looking at.  There is a significant amount of information that momo (the tool) needs to know about a module in order to be able to interact with it in a pleasing way.  Currently this is:

- the module's python proxy object (now in pymomo/commander/proxy)
- the module's log statement definitions (this will be more clear after the PR but these define the types and specified formatting of all of the log entries so that momo can interpret the log data in a way other than just strings, numbers and binary blobs (now stored in the src directory of each module since it's also needed in the build process)
- the module's symbol map (needed for fetching variables from live modules via name, mapping addresses to symbols in log entries).  This is currently a byproduct of the build process for pic12 modules and a .map file for pic24 that I haven't yet processed into a usable object)

You'll need these three bits of information from each module you want to interact with.  Bit 1 could be constructed on the fly from inspecting the module's RPC endpoints but it won't be as nice as what you would get from a custom proxy object with annotated types, validation of arguments, added features and doc strings).  I think it would be good to have these all stored with each module so that there are no global dependencies, i.e. the mainboard directory contains everything you need to interact with the mainboard.  But this requires telling the momo tool about those proxy objects, log definitions and symbols.  This can all be done with calls in the momo tool itself and currently that's what I do for the log definition files but it's verbose to have to call those functions each time you open the tool.  So the idea I had was to have a .momorc file similar to .bashrc that is invoked whenever you run the momo tool and you could use to preload log definitions, symbol files and proxy objects for modules that you commonly use.  This shouldn't limit customizability because there's nothing special about our modules and someone's special modules that they make later and there's no magic in the config file.  It's just making momo calls you could make yourself but doing them for you so you don't have to everytime.

Does this make sense or do you have a thought for how we could achieve this in a better way?  I see this as a way of getting the proxy objects for the modules out of pymomo and into each module where they belong (I think) without sacrificing usability or customizability.

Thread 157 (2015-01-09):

Finish module reset functionality by toggling ALARM pin

timburke, 2015-01-09:
The momo controller resets the modules on the bus by toggling the ALARM pin low for 10 microseconds.  This is currently disabled on pic16lf1847.  Test hotplugging situations to see if there are ALARM pin transients and then enable this code on all of the modules so that the new GSM module has it.

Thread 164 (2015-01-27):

New system log appears to be broken

amcgee, 2015-01-27:
Running `momo controller read_log` throws the following error:

```
ValidationError: Buffer must be of length sizeof(GenericLogEntry) = 16 bytes
Additional Information:
buffer: 3=?(
```

Running clear_log and then read_log accesses the SystemLog momo context but running `momo controller read_log help` fails like so:

```
(SystemLog) help

SystemLog
A list of log entries from the MoMo system log

The MoMo controller keeps an ordered list of timestamped
logged events, which can contain arbitrary parameters.
This class encapsulates one such list and allows you to
access, filter and display the log entries.

Defined Functions:
Traceback (most recent call last):
  File "/usr/local/bin/momo", line 9, in <module>
    load_entry_point('pymomo==1.0.4', 'console_scripts', 'momo')()
  File "/usr/local/lib/python2.7/dist-packages/pymomo/scripts/momo.py", line 88, in main
    line, finished = shell.invoke(line)
  File "/usr/local/lib/python2.7/dist-packages/pymomo/utilities/typedargs/shell.py", line 267, in invoke
    return _do_help(context, line)
  File "/usr/local/lib/python2.7/dist-packages/pymomo/utilities/typedargs/shell.py", line 108, in _do_help
    print_dir(context)
  File "/usr/local/lib/python2.7/dist-packages/pymomo/utilities/typedargs/shell.py", line 84, in print_dir
    print " - " + annotate.get_signature(fun)
  File "/usr/local/lib/python2.7/dist-packages/pymomo/utilities/typedargs/annotate.py", line 128, in get_signature
    name = f.__name__
AttributeError: LogDefinitionMap instance has no attribute '__name__'
```

Finally, running `momo controller reset` and then `momo controller read_log` again results in the original ValidationError.

This is running controller firmware v4.1 from the latest dev branch on the newest hardware version.

amcgee, 2015-02-01:
This has been resolved.

Closed 2015-02-01.

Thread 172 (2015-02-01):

GSM module can sometimes cause MoMo to be reset while attempting to register

amcgee, 2015-02-01:
This seems to be caused by poor network conditions and/or bad antenna positioning.  This was causing memory corruption errors before the log initialization order fix was introduced.

timburke, 2015-02-01:
This is bad.  I'll need to connect an oscilloscope and see what's going on.

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

amcgee, 2015-02-01:
Agreed

amcgee, 2015-03-14:
We've determined that this is an RF feedback issue reincarnate.

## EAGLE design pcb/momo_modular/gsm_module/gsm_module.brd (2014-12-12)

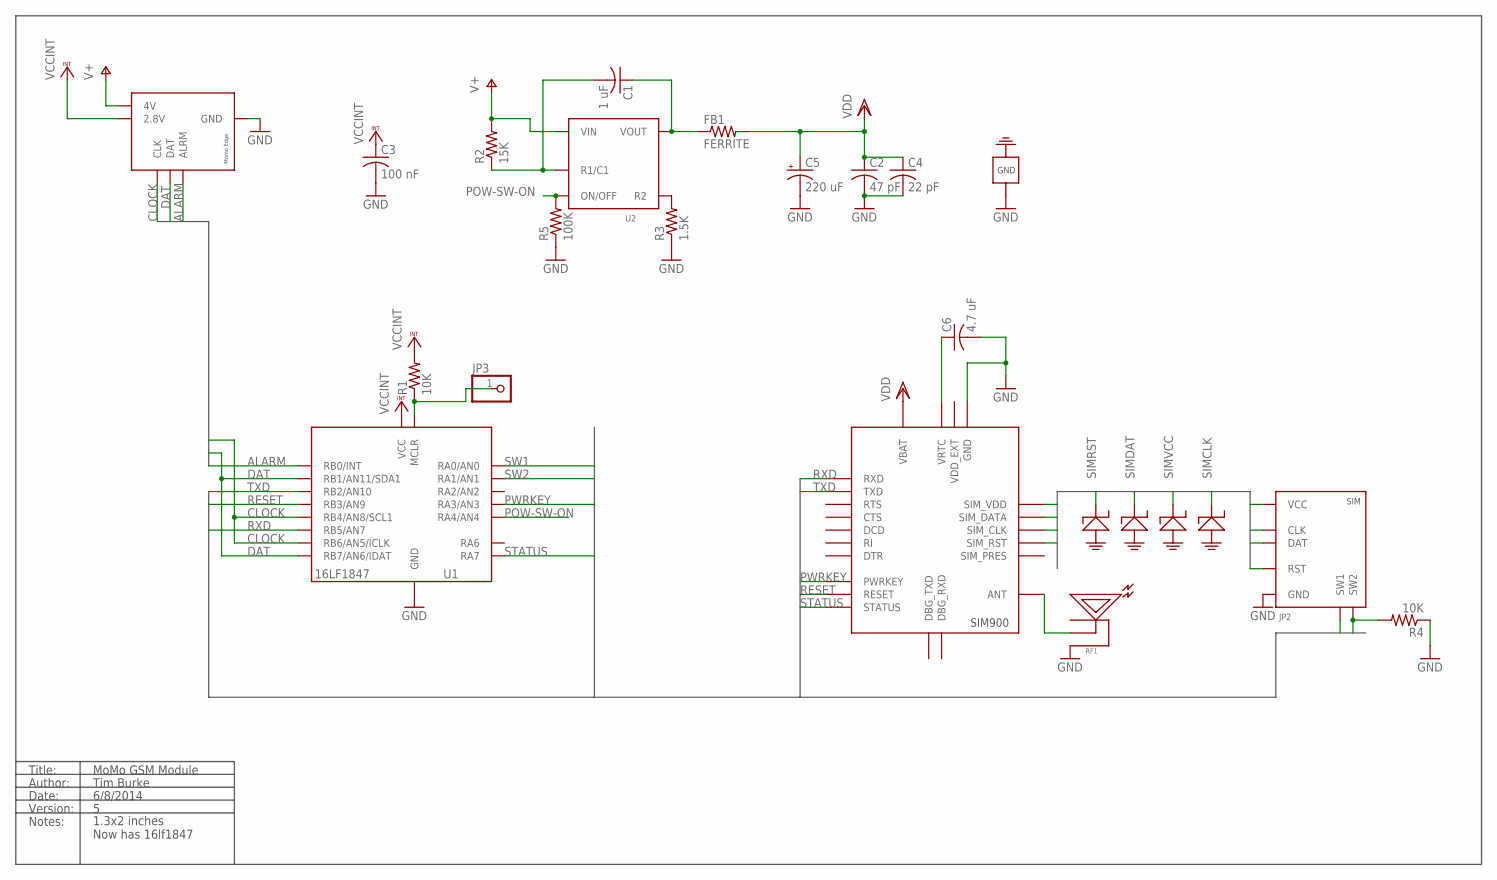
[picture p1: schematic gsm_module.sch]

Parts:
C1: 1 uF; C0402K; DIGIKEY-PN 445-4114-1-ND
C2: 47 pF; C0402K; DIGIKEY-PN 445-1243-1-ND
C3: 100 nF; C0402; DIGIKEY-PN 445-1265-1-ND
C4: 22 pF; C0402K; DIGIKEY-PN 445-1239-1-ND
C5: 220 uF; CT3528
C6: 4.7 uF; C0805; DIGIKEY-PN 1276-1259-1-ND
FB1: FERRITE; R0805; DIGIKEY-PN 445-1567-1-ND
JP1: MOMO-EDGE-6M
JP2: SIMHOLDER-8PINMICROSIM; MOLEX-MICROSIM-0787270001
JP3: PINHD-1X1; 1X01
R1, R4: 10K; R0603; DIGIKEY-PN P10.0KHCT-ND
R2: 15K; R0603; DIGIKEY-PN P15KGCT-ND
R3: 1.5K; R0603; DIGIKEY-PN P1.5KGCT-ND
R5: 100K; R0603; DIGIKEY-PN P100KHCT-ND
RF1: RFANTENNA; RFJACK; DIGIKEY-PN J983CT-ND
U1: PIC16LF1847; SSOP20
U2: TI-HIGHSIDE-PFET; SOT23-6L
U3: SIM900
U4: ESD-SMF05C; SC70-6L

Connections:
ALARM: JP1.ALARM (ALRM), U1.7 (RB0/INT)
CLOCK: JP1.CLK, U1.11 (RB4/AN8/SCL1), U1.13 (RB6/AN5/ICLK)
DAT: JP1.DAT, U1.8 (RB1/AN11/SDA1), U1.14 (RB7/AN6/IDAT)
GND: C2.2, C3.2, C4.2, C5.-, C6.2, JP1.GND, JP2.C5 (GND), JP2.GND1 (GND), JP2.GND2 (GND), JP2.GND3 (GND), JP2.GND4 (GND), JP2.GND5 (GND), JP2.GND6 (GND), R3.1, R4.1, R5.1, RF1.UNUSED1 (SHIELD), RF1.UNUSED2 (SHIELD), U1.5 (GND), U1.6 (GND), U3.17 (GND), U3.18 (GND), U3.29 (GND), U3.39 (GND), U3.45 (GND), U3.46 (GND), U3.53 (GND), U3.54 (GND), U3.58 (GND), U3.59 (GND), U3.61 (GND), U3.62 (GND), U3.63 (GND), U3.64 (GND), U3.65 (GND), U4.2 (GND)
unnamed: R3.2, U2.1 (R2)
unnamed: JP3.1, R1.1, U1.4 (MCLR)
unnamed: C1.2, R2.1, U2.6 (R1/C1)
unnamed: C1.1, FB1.1, U2.2 (VOUT), U2.3 (VOUT)
unnamed: C6.1, U3.26 (VRTC)
unnamed: RF1.ANTENNA (PIN), U3.60 (ANT)
POW-SW-ON: R5.2, U1.3 (RA4/AN4), U2.5 (ON/OFF)
PWRKEY: U1.2 (RA3/AN3), U3.1 (PWRKEY)
RESET: U1.10 (RB3/AN9), U3.16 (RESET)
RXD: U1.12 (RB5/AN7), U3.10 (RXD)
SIMCLK: JP2.C3 (CLK), U3.32 (SIM_CLK), U4.3
SIMDAT: JP2.C7 (DAT), U3.31 (SIM_DATA), U4.5
SIMRST: JP2.C2 (RST), U3.33 (SIM_RST), U4.1
SIMVCC: JP2.C1 (VCC), U3.30 (SIM_VDD), U4.4
STATUS: U1.18 (RA7), U3.66 (STATUS)
SW1: JP2.DCONT (SW1), U1.19 (RA0/AN0)
SW2: JP2.DSPRING (SW2), R4.2, U1.20 (RA1/AN1)
TXD: U1.9 (RB2/AN10), U3.9 (TXD)
V+: JP1.4V, R2.2, U2.4 (VIN)
VCCINT: C3.1, JP1.V28 (2.8V), R1.2, U1.15 (VCC), U1.16 (VCC)
VDD: C2.1, C4.1, C5.+, FB1.2, U3.55 (VBAT), U3.56 (VBAT), U3.57 (VBAT)
VDD_EXT: U3.15 (VDD_EXT)

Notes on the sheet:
Title:
Author:
Date:
Version:
Notes:
MoMo GSM Module
Tim Burke
6/8/2014
1.3x2 inches Now has 16lf1847

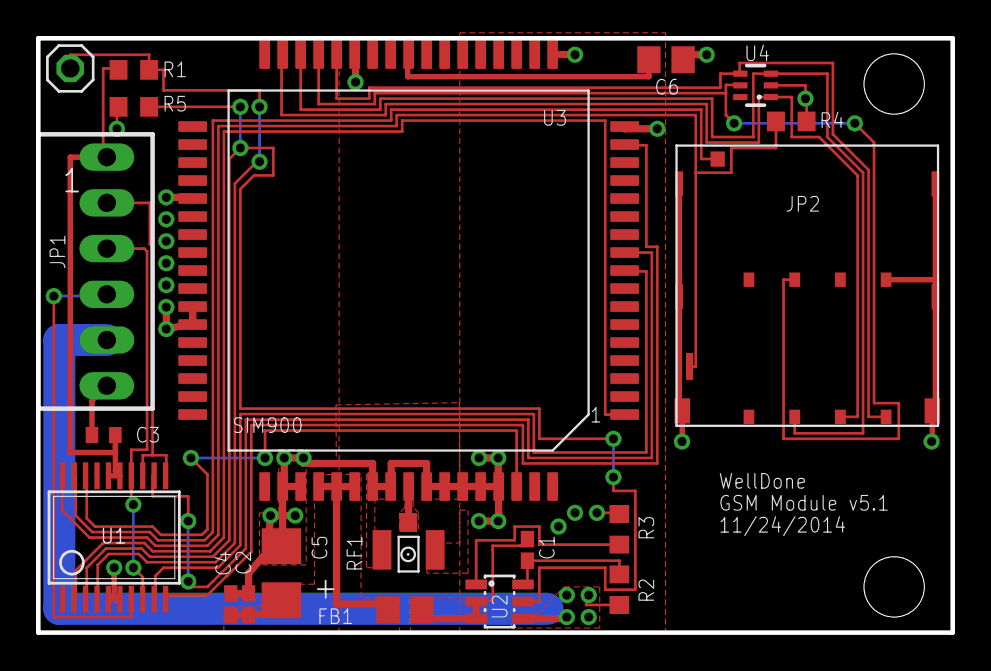
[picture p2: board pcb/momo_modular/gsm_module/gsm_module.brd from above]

Board: 2 copper layers, 50.8 x 33.0 mm, 20 parts (0 on the bottom side), 25 nets.

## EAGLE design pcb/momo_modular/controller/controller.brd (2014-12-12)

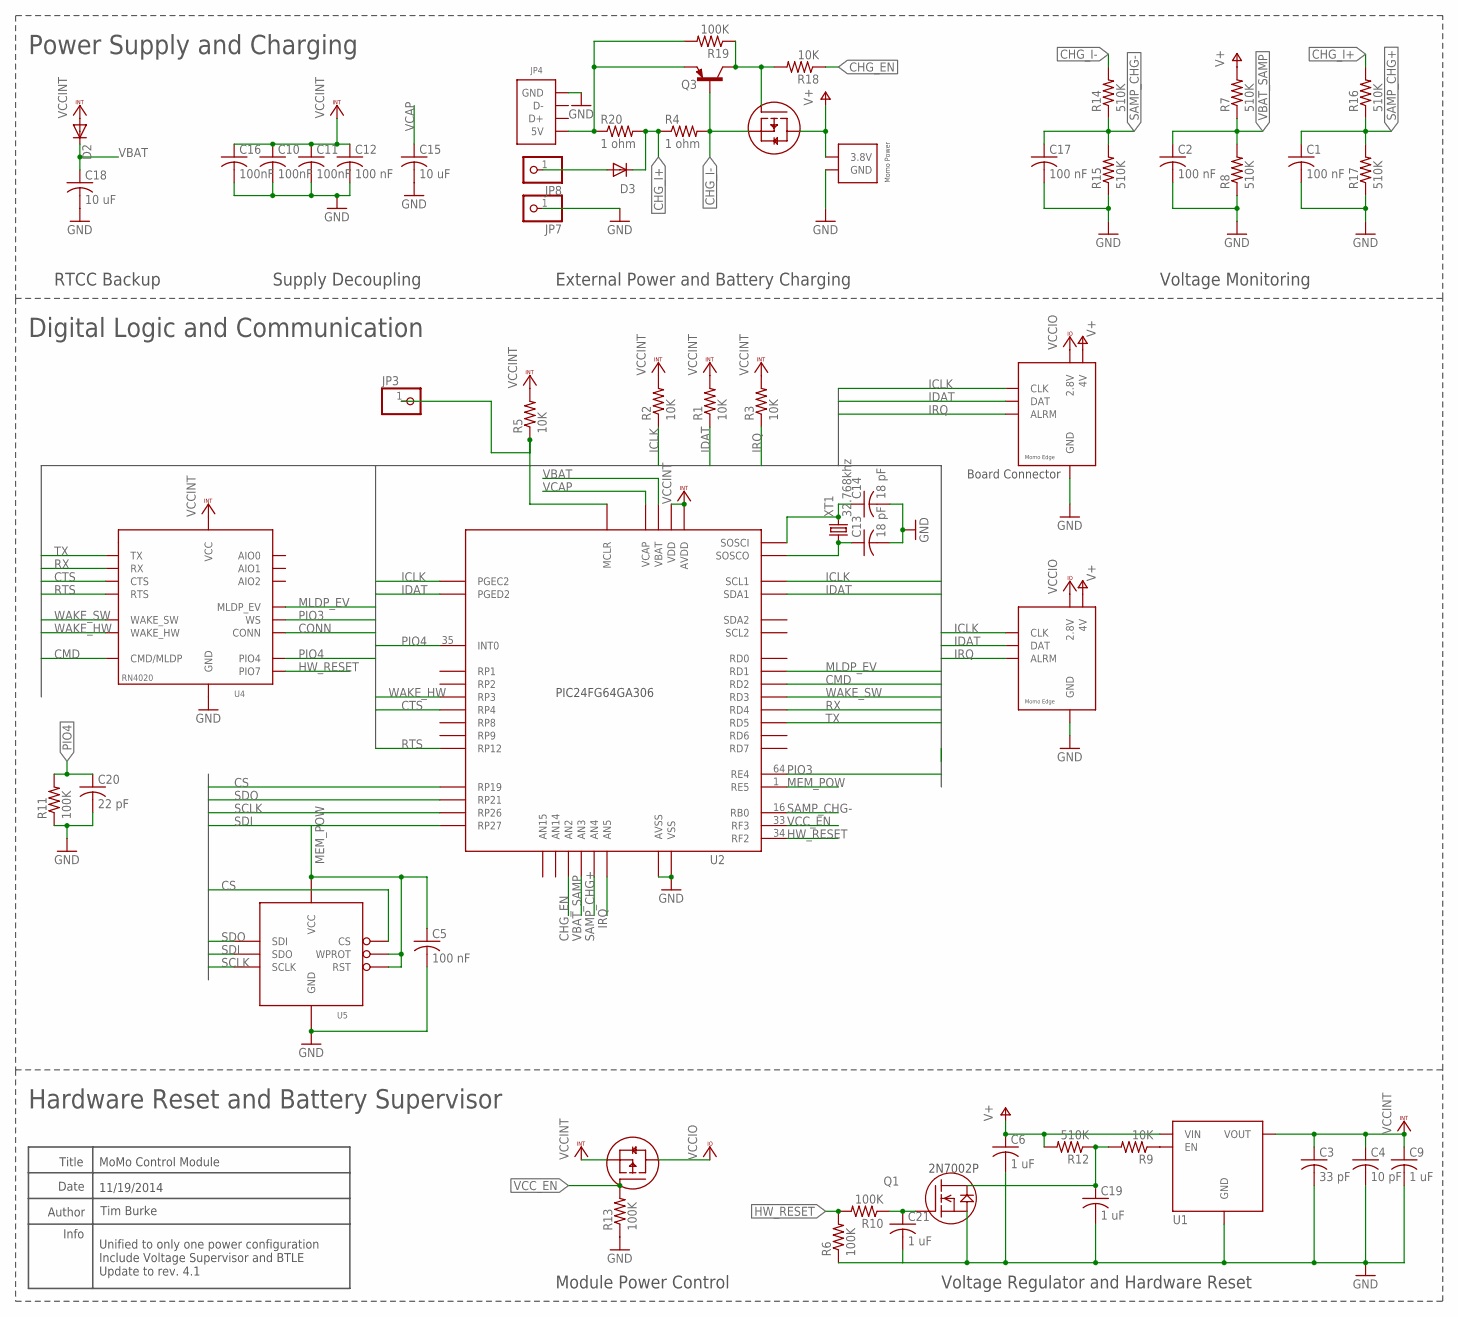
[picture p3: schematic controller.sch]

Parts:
C1, C2, C5, C12, C17: 100 nF; C0402K; DIGIKEY-PN 445-1265-1-ND
C3: 33 pF; C0402K; DIGIKEY-PN 1276-1272-1-ND
C4: 10 pF; C0402K; DIGIKEY-PN 1276-1139-1-ND
C6, C9, C19, C21: 1 uF; C0402K; DIGIKEY-PN 445-4114-1-ND
C10, C11, C16: 100nF; C0402K; DIGIKEY-PN 445-1265-1-ND
C13, C14: 18 pF; C0402K; DIGIKEY-PN 445-1238-1-ND
C15, C18: 10 uF; C0805K; DIGIKEY-PN 1276-2893-1-ND
C20: 22 pF; C0402K; DIGIKEY-PN 1276-1116-1-ND
D2, D3: DIODE-SC79_INFINEON; SC79_INFINEON
JP1: MOMO-VERT-6M; 1X06; DIGIKEY-PN S1011EC-06-ND
JP2: MOMO-EDGE-6F; MOMO-EDGE-8F
JP3, JP7, JP8: PINHD-1X1; 1X01
JP4: CONN-MICROUSB-B-RCPT; MICROUSB-B-FCI
JP5: MOMO-PWR-HOUSED
Q1: MOSFET-N; SOT-23; DIGIKEY-PN 568-5818-1-ND
Q2, Q4: P-MOSFET; SOT23; DIGIKEY-PN IRLML6402PBFCT-ND
Q3: MMBTA56-SOT23; SOT23; DIGIKEY-PN 568-1742-1-ND
R1, R2, R3, R5, R9, R18: 10K; R0603; DIGIKEY-PN P10.0KHCT-ND
R4, R20: 1 ohm; R1206; DIGIKEY-PN 311-1.00FRCT-ND
R6, R10, R11, R13, R19: 100K; R0603; DIGIKEY-PN P100KHCT-ND
R7, R8, R12, R14, R15, R16, R17: 510K; R0603; DIGIKEY-PN P510KHCT-ND
U1: XC6504-LINEAR-REGULATOR; SOT23-5L
U2: PIC24FJ64GA306; TQFP64-10X10
U4: RN4020_BT_4.0_MODULE; RN20-BTLE-MODULE
U5: FLASH8MSOP8; SOP08; DIGIKEY-PN M25PX80-VMN6TPCT-ND
XT1: 32.768khz; TC26H; DIGIKEY-PN 535-9034-ND

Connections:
CHG_EN: R18.1, U2.14 (AN2)
CHG_I+: D3.C, R4.1, R16.2, R20.2
CHG_I-: Q3.1 (B), Q4.2 (SOURCE), R4.2, R14.2
CMD: U2.50 (RD2), U4.CMD/MLDP
CONN: U4.PIO1 (CONN)
CS: U2.6 (RP19), U5.1 (CS)
CTS: U2.43 (RP4), U4.PIO5 (CTS)
GND: C1.2, C2.2, C3.2, C4.2, C5.2, C6.2, C9.2, C10.2, C11.2, C12.2, C13.2, C14.2, C15.2, C16.2, C17.2, C18.2, C19.2, C20.2, C21.2, JP1.7 (GND), JP2.GND, JP4.5 (GND), JP4.GND2 (GND), JP4.GND3 (GND), JP4.GND4 (GND), JP4.GND5 (GND), JP4.GND6 (GND), JP5.2 (GND), JP7.1, Q1.2 (S), R6.1, R8.1, R11.1, R13.1, R15.1, R17.1, U1.2 (GND), U2.9 (VSS), U2.20 (AVSS), U2.25 (VSS), U2.41 (VSS), U4.GND, U4.GND1 (GND), U4.SHIELD1 (GND), U4.SHIELD2 (GND), U4.SHIELD3 (GND), U4.SHIELD4 (GND), U5.4 (GND)
HW_RESET: R6.2, R10.2, U2.34 (RF2), U4.PIO7
ICLK: JP1.3 (CLK), JP2.CLK, R2.1, U2.17 (PGEC2), U2.37 (SCL1)
IDAT: JP1.4 (DAT), JP2.DAT, R1.1, U2.18 (PGED2), U2.36 (SDA1)
IRQ: JP1.5 (ALRM), JP2.ARLM (ALRM), R3.1, U2.11 (AN5)
MEM_POW: C5.1, U2.1 (RE5), U5.3 (WPROT), U5.7 (RST), U5.8 (VCC)
MLDP_EV: U2.49 (RD1), U4.PIO2 (MLDP_EV)
unnamed: R9.1, U1.3 (EN)
unnamed: C21.1, Q1.1 (G), R10.1
unnamed: D3.A, JP8.1
unnamed: JP3.1, R5.1, U2.7 (MCLR)
unnamed: JP4.1 (5V), Q3.2 (E), R19.2, R20.1
unnamed: C14.1, U2.47 (SOSCI), XT1.2
unnamed: C13.1, U2.48 (SOSCO), XT1.1
unnamed: Q3.3 (C), Q4.1 (GATE), R18.2, R19.1
unnamed: C19.1, Q1.3 (D), R9.2, R12.1
PIO3: U2.64 (RE4), U4.PIO3 (WS)
PIO4: C20.1, R11.2, U2.35 (INT0), U4.PIO4
RTS: U2.45 (RP12), U4.RTS/PIO6 (RTS)
RX: U2.52 (RD4), U4.UART_RX (RX)
SAMP_CHG+: C1.1, R16.1, R17.2, U2.12 (AN4)
SAMP_CHG-: C17.1, R14.1, R15.2, U2.16 (RB0)
SCLK: U2.5 (RP26), U5.6 (SCLK)
SDI: U2.8 (RP27), U5.2 (SDO)
SDO: U2.4 (RP21), U5.5 (SDI)
TX: U2.53 (RD5), U4.UART_TX (TX)
V+: C6.1, JP1.6 (4V), JP2.V4 (4V), JP5.1 (3.8V), Q4.3 (DRAIN), R7.2, R12.2, U1.1 (VIN)
VBAT: C18.1, D2.C, U2.57 (VBAT)
VBAT_SAMP: C2.1, R7.1, R8.2, U2.13 (AN3)
VCAP: C15.1, U2.56 (VCAP)
VCCINT: C3.1, C4.1, C9.1, C10.1, C11.1, C12.1, C16.1, D2.A, Q2.2 (SOURCE), R1.2, R2.2, R3.2, R5.2, U1.5 (VOUT), U2.10 (VDD), U2.19 (AVDD), U2.26 (VDD), U2.38 (VDD), U4.VDD (VCC)
VCCIO: JP1.1 (2.8V), JP2.V28 (2.8V), Q2.3 (DRAIN)
VCC_EN: Q2.1 (GATE), R13.2, U2.33 (RF3)
WAKE_HW: U2.44 (RP3), U4.WAKE_HW
WAKE_SW: U2.51 (RD3), U4.WAKE_SW

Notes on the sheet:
Title
Author
Date
Tim Burke
Info
Board Connector
MoMo Control Module
11/19/2014
Unified to only one power configuration Include Voltage Supervisor and BTLE Update to rev. 4.1
Power Supply and Charging
Digital Logic and Communication
Voltage Monitoring
External Power and Battery Charging
Supply Decoupling
RTCC Backup
Hardware Reset and Battery Supervisor
Module Power Control
Voltage Regulator and Hardware Reset
2N7002P

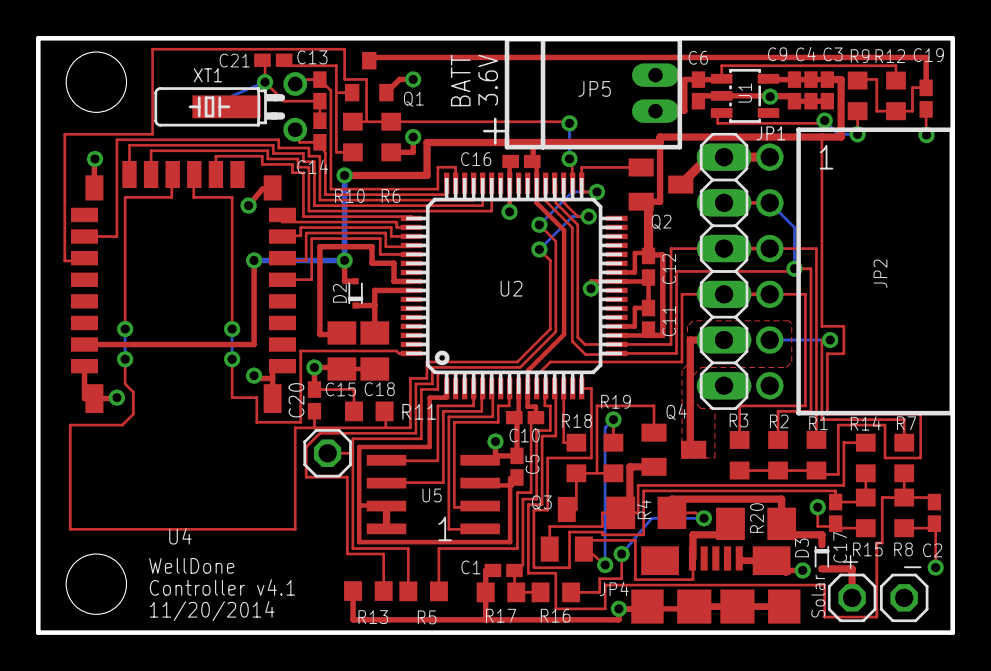
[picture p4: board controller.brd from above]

Board: 2 copper layers, 50.8 x 33.0 mm, 57 parts (0 on the bottom side), 41 nets.

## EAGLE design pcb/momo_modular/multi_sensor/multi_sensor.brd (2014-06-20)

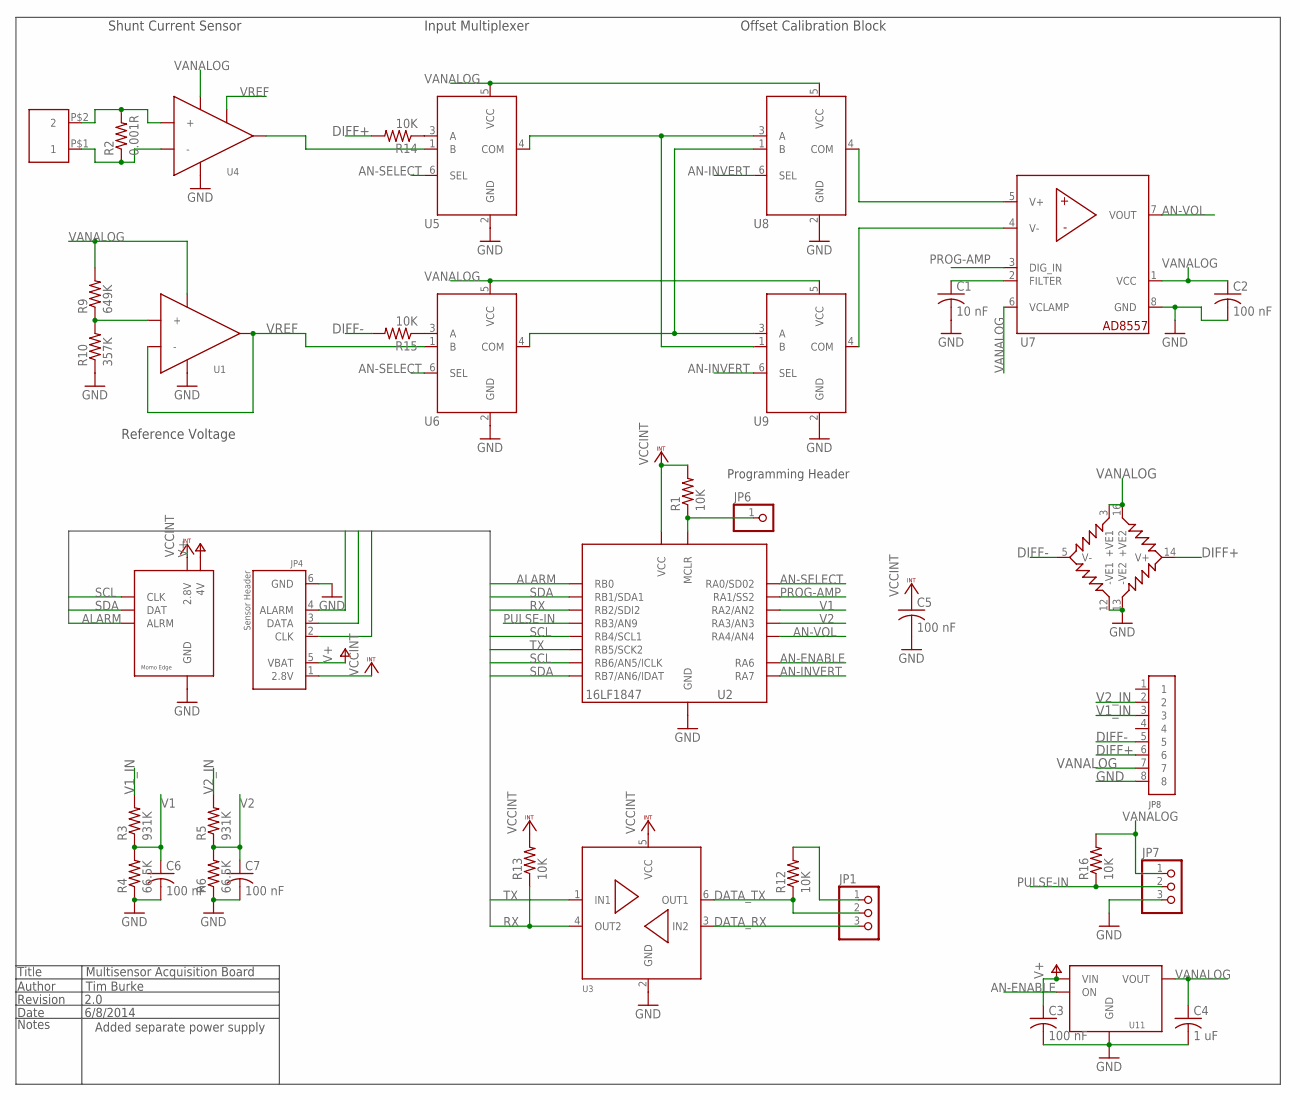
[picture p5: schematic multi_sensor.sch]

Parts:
C1: 10 nF; C0402; DIGIKEY-PN 490-6286-1-ND
C2, C3, C5, C6, C7: 100 nF; C0402K; DIGIKEY-PN 445-1265-1-ND
C4: 1 uF; C0402K; DIGIKEY-PN 445-4114-1-ND
JP1, JP7: PINHD-1X3; 1X03
JP2: MOMO-VERT-6M; 1X06; DIGIKEY-PN S7004-ND
JP3: 5MM-SCREWTERM-2POS; 5MM-SCREWTERM
JP4: MOMO-SENSOR-RJ11; RJ-12; DIGIKEY-PN AE10371-ND
JP6: PINHD-1X1; 1X01
JP8: 8PIN-TERMBLOCK-PUSH; 8-PIN-TERMBLOCK-PUSH
R1, R12, R13, R14, R15, R16: 10K; R0603; DIGIKEY-PN P10.0KHCT-ND
R2: 0.001R; R2512; DIGIKEY-PN CRF2512-FV-R001ELFCT-ND
R3, R5: 931K; R0603; DIGIKEY-PN RHM931KCLCT-ND
R4, R6: 66.5K; R0603; DIGIKEY-PN RC0603FR-0766K5L
R9: 649K; R0603; DIGIKEY-PN 311-649KHRCT-ND
R10: 357K; R0603; DIGIKEY-PN RC0603FR-07357KL
U1: MCP6001U; SOT23-5L
U2: 16LF1847; SSOP20; DIGIKEY-PN PIC16LF1847-I/SS-ND
U3: DUAL-BUFFER-OD-NC7WZ07; SC70-6L
U4: LT1990; SOP08
U5, U6, U8, U9: 2:1-MUX; SOT363_INFINEON
U7: AD8557-DIGITRIM-OPAMP; SOIC8
U10: SM5470-DIFF-PRESS-SENSOR; SO16W
U11: TCR2EF28-LINREG; SC74A-5PIN

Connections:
ALARM: JP2.5 (ALRM), JP4.4 (ALARM), U2.7 (RB0)
AN-ENABLE: U2.17 (RA6), U11.3 (ON)
AN-INVERT: U2.18 (RA7), U8.6 (SEL), U9.6 (SEL)
AN-SELECT: U2.19 (RA0/SD02), U5.6 (SEL), U6.6 (SEL)
AN-VOL: U2.3 (RA4/AN4), U7.7 (VOUT)
DATA_RX: JP1.3, U3.3 (IN2)
DATA_TX: JP1.2, R12.1, U3.6 (OUT1)
DIFF+: JP8.6, R14.2, U10.14 (V+)
DIFF-: JP8.5, R15.2, U10.5 (V-)
GND: C1.2, C2.2, C3.2, C4.2, C5.2, C6.2, C7.2, JP2.7 (GND), JP4.6 (GND), JP7.3, JP8.8, R4.1, R6.1, R10.1, U1.2 (GND), U2.5 (GND), U2.6 (GND), U3.2 (GND), U4.4 (GND), U5.2 (GND), U6.2 (GND), U7.8 (GND), U8.2 (GND), U9.2 (GND), U10.12 (-VE1), U10.13 (-VE2), U11.2 (GND)
unnamed: JP1.1, R12.2
unnamed: R9.1, R10.2, U1.1 (+)
unnamed: JP6.1, R1.1, U2.4 (MCLR)
unnamed: U5.4 (COM), U8.3 (A), U9.1 (B)
unnamed: R14.1, U5.3 (A)
unnamed: C1.1, U7.2 (FILTER)
unnamed: U6.4 (COM), U8.1 (B), U9.3 (A)
unnamed: R15.1, U6.3 (A)
unnamed: U7.5 (V+), U8.4 (COM)
unnamed: U7.4 (V-), U9.4 (COM)
unnamed: U4.6 (OUT), U5.1 (B)
PROG-AMP: U2.20 (RA1/SS2), U7.3 (DIG_IN)
PULSE-IN: JP7.2, R16.1, U2.10 (RB3/AN9)
RS+: JP3.P$1 (1), R2.1, U4.2 (-)
RS-: JP3.P$2 (2), R2.2, U4.3 (+)
RX: R13.1, U2.9 (RB2/SDI2), U3.4 (OUT2)
SCL: JP2.3 (CLK), JP4.2 (CLK), U2.11 (RB4/SCL1), U2.13 (RB6/AN5/ICLK)
SDA: JP2.4 (DAT), JP4.3 (DATA), U2.8 (RB1/SDA1), U2.14 (RB7/AN6/IDAT)
TX: U2.12 (RB5/SCK2), U3.1 (IN1)
V1: C6.1, R3.1, R4.2, U2.1 (RA2/AN2)
V1_IN: JP8.3, R3.2
V2: C7.1, R5.1, R6.2, U2.2 (RA3/AN3)
V2_IN: JP8.2, R5.2
V+: C3.1, JP2.6 (4V), JP4.5 (VBAT), U11.1 (VIN)
VANALOG: C2.1, C4.1, JP7.1, JP8.7, R9.2, R16.2, U1.5 (VCC), U4.7 (VCC), U5.5 (VCC), U6.5 (VCC), U7.1 (VCC), U7.6 (VCLAMP), U8.5 (VCC), U9.5 (VCC), U10.3 (+VE1), U10.16 (+VE2), U11.5 (VOUT)
VCCINT: C5.1, JP2.1 (2.8V), JP4.1 (2.8V), R1.2, R13.2, U2.15 (VCC), U2.16 (VCC), U3.5 (VCC)
VREF: U1.3 (-), U1.4 (OUT), U4.1 (SHUT), U6.1 (B)

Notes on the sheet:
Title
Author
Revision
Date
Notes
Multisensor Acquisition Board
Tim Burke
2.0
6/8/2014
Programming Header
Offset Calibration Block
Input Multiplexer
Shunt Current Sensor
Reference Voltage
Added separate power supply

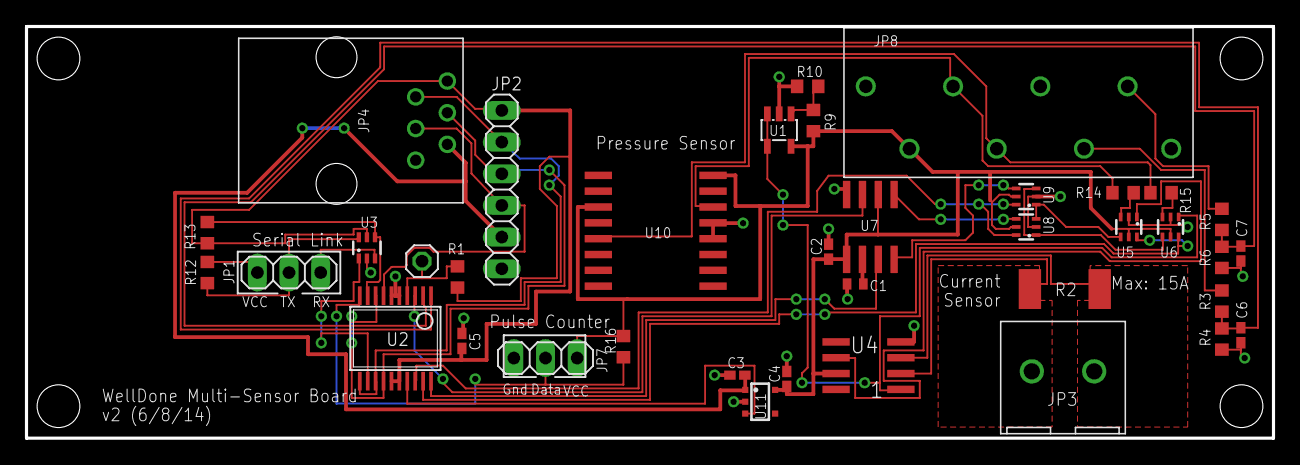
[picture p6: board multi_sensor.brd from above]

Board: 2 copper layers, 100.0 x 33.0 mm, 38 parts (0 on the bottom side), 37 nets.

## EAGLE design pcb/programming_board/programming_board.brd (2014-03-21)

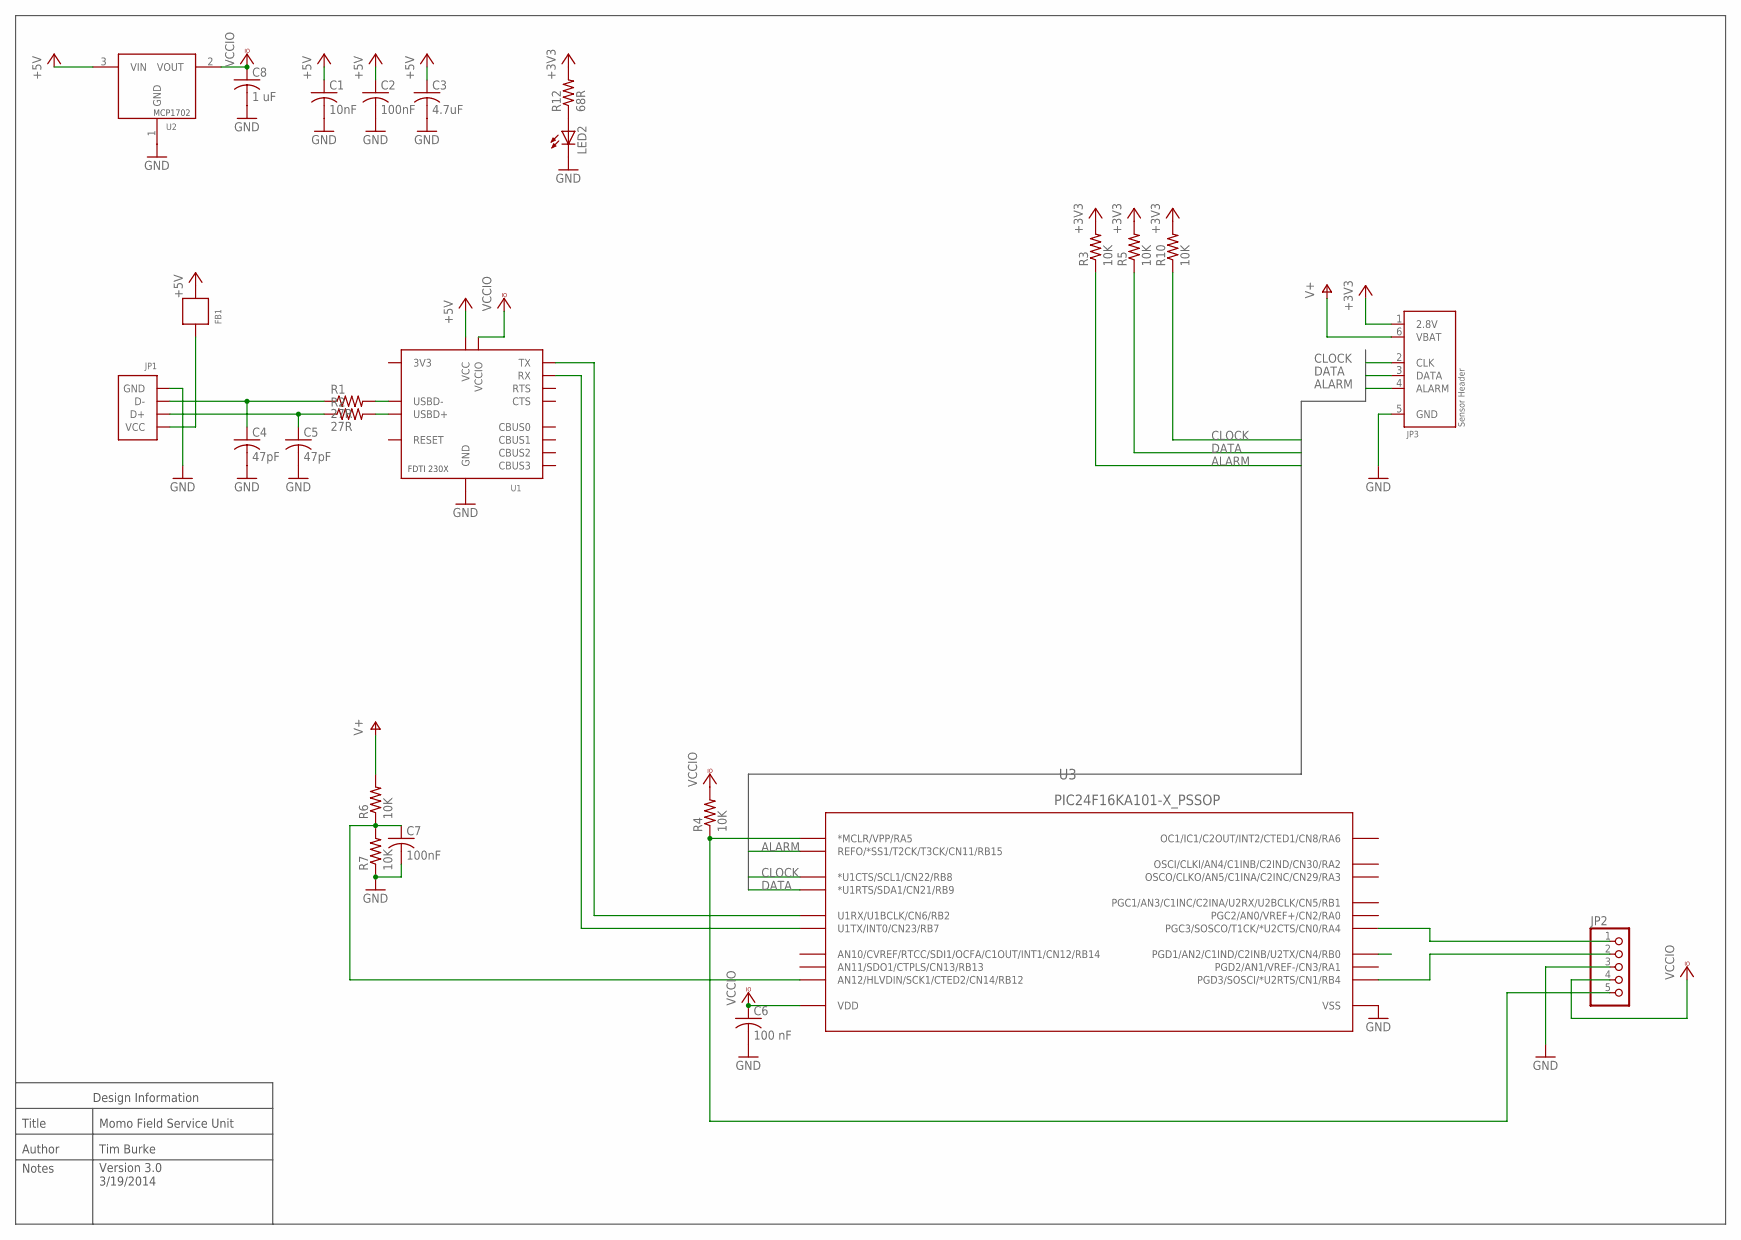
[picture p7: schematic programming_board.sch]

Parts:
C1: 10nF; C0402; DIGIKEY-PN 1276-1499-1-ND
C2, C7: 100nF; C0402; DIGIKEY-PN 445-1265-1-ND
C3: 4.7uF; C0805; DIGIKEY-PN 445-1605-1-ND
C4, C5: 47pF; C0402; DIGIKEY-PN 1276-1699-1-ND
C6: 100 nF; C0402; DIGIKEY-PN 445-1265-1-ND
C8: 1 uF; C0402; DIGIKEY-PN 1276-1076-1-ND
FB1: FERRITE; R0805; DIGIKEY-PN 240-2390-1-ND
JP1: MOLEX-USB-CONN; USB-MALE-EDGE
JP2: PINHD-1X5; 1X05
JP3: MOMO-SENSOR-RJ11-VERT; RJ12-VERT
LED2: LEDSML0603; SML0603; DIGIKEY-PN 475-1409-1-ND
R1, R2: 27R; R0603; DIGIKEY-PN P27.0HCT-ND
R3, R4, R5, R6, R7, R10: 10K; R0603; DIGIKEY-PN P10.0KHCT-ND
R12: 68R; R0603; DIGIKEY-PN P68GCT-ND
U1: FTDI-230X; SSOP16; DIGIKEY-PN 768-1135-1-ND
U2: MCP1702; SOT23
U3: PIC24F16KA101-X_PSSOP; SSOP20; DIGIKEY-PN PIC24F16KA101-I/SS-ND

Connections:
+3V3: JP3.1 (2.8V), R3.2, R5.2, R10.2, R12.2
+5V: C1.1, C2.1, C3.1, FB1.2 (OUT), U1.12 (VCC), U2.3 (VIN)
ALARM: JP3.4 (ALARM), R3.1, U3.18 (REFO/*SS1/T2CK/T3CK/CN11/RB15)
CLOCK: JP3.2 (CLK), R10.1, U3.12 (*U1CTS/SCL1/CN22/RB8)
CLOCKRX: U3.4 (PGD1/AN2/C1IND/C2INB/U2TX/CN4/RB0)
DATA: JP3.3 (DATA), R5.1, U3.13 (*U1RTS/SDA1/CN21/RB9)
GND: C1.2, C2.2, C3.2, C4.2, C5.2, C6.2, C7.2, C8.2, JP1.4 (GND), JP2.3, JP3.5 (GND), LED2.C, R7.1, U1.5 (GND), U1.13 (GND), U2.1 (GND), U3.19 (VSS)
unnamed: C4.1, JP1.2 (D-), R1.1
unnamed: FB1.1 (IN), JP1.1 (VCC)
unnamed: C5.1, JP1.3 (D+), R2.1
unnamed: R1.2, U1.9 (USBD-)
unnamed: R2.2, U1.8 (USBD+)
unnamed: LED2.A, R12.1
unnamed: JP2.1, U3.10 (PGC3/SOSCO/T1CK/*U2CTS/CN0/RA4)
unnamed: JP2.2, U3.9 (PGD3/SOSCI/*U2RTS/CN1/RB4)
unnamed: C7.1, R6.1, R7.2, U3.15 (AN12/HLVDIN/SCK1/CTED2/CN14/RB12)
unnamed: JP2.5, R4.1, U3.1 (*MCLR/VPP/RA5)
PICRX1: U1.1 (TX), U3.6 (U1RX/U1BCLK/CN6/RB2)
PICTX1: U1.4 (RX), U3.11 (U1TX/INT0/CN23/RB7)
V+: JP3.6 (VBAT), R6.2
VCCIO: C6.1, C8.1, JP2.4, R4.2, U1.3 (VCCIO), U2.2 (VOUT), U3.20 (VDD)

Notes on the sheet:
Tim Burke
Author
Title
Momo Field Service Unit
Notes
Version 3.0 3/19/2014
Design Information

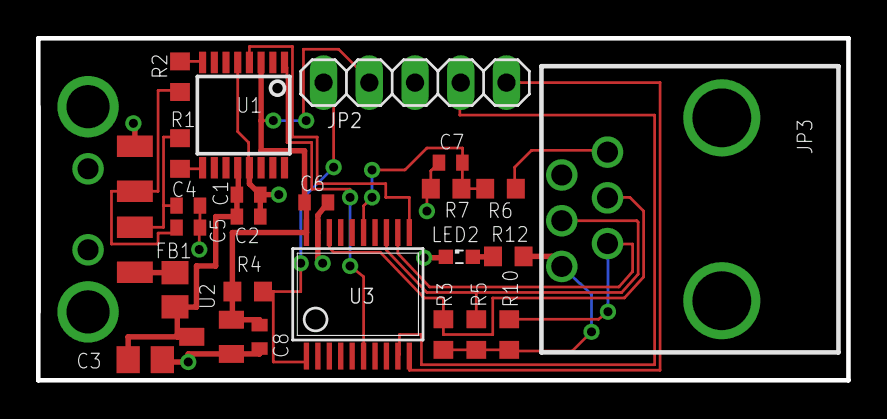
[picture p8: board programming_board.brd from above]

Board: 2 copper layers, 45.0 x 19.0 mm, 25 parts (0 on the bottom side), 20 nets.

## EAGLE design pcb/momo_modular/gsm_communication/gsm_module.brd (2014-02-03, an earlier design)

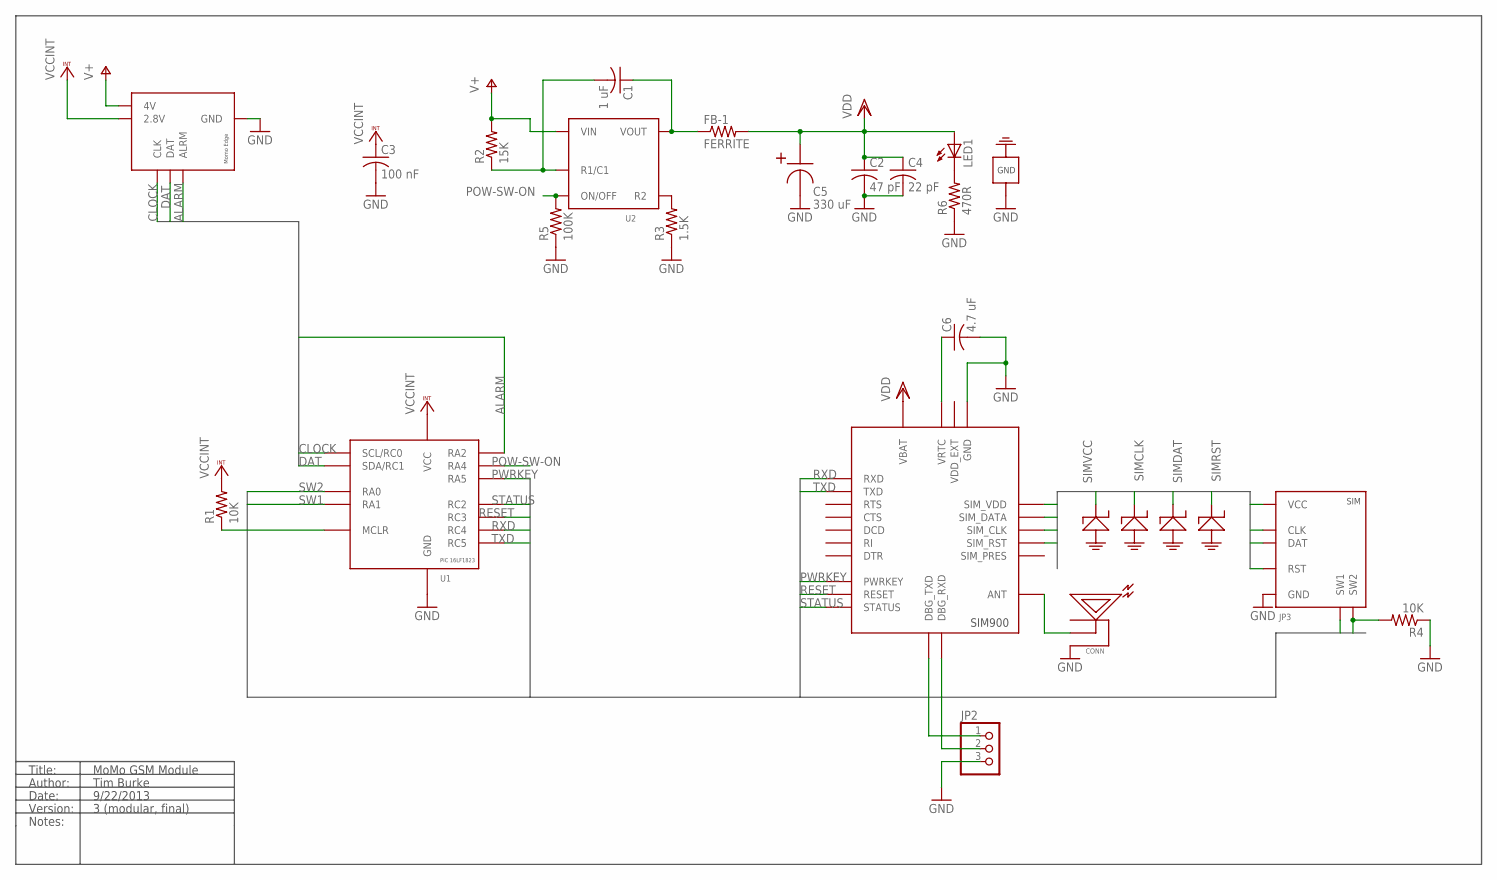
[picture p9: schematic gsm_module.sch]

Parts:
C1: 1 uF; C0402K; DIGIKEY-PN 445-4114-1-ND
C2: 47 pF; C0402K; DIGIKEY-PN 445-1243-1-ND
C3: 100 nF; C0402; DIGIKEY-PN 445-1265-1-ND
C4: 22 pF; C0402K; DIGIKEY-PN 445-1239-1-ND
C5: 330 uF; 2917
C6: 4.7 uF; C0805; DIGIKEY-PN 1276-1259-1-ND
CONN: RFANTENNA; RFJACK; DIGIKEY-PN J983CT-ND
FB-1: FERRITE; R0805; DIGIKEY-PN 445-1567-1-ND
JP1: MOMO-EDGE-6M
JP2: PINHD-1X3; 1X03
JP3: SIMHOLDER-8PINHING; CCM03-SIMHOLDER
LED1: LEDCHIPLED_0603; CHIPLED_0603; DIGIKEY-PN 475-2709-1-ND
R1, R4: 10K; R0603; DIGIKEY-PN P10.0KHCT-ND
R2: 15K; R0603; DIGIKEY-PN P15KGCT-ND
R3: 1.5K; R0603; DIGIKEY-PN P1.5KGCT-ND
R5: 100K; R0603; DIGIKEY-PN P100KHCT-ND
R6: 470R; R0603
U1: PIC16LF1823; SO14; DIGIKEY-PN PIC16LF1823-I/SL-ND
U2: TI-HIGHSIDE-PFET; SOT23-6L
U3: SIM900
U4: ESD-SMF05C; SC70-6L

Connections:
ALARM: JP1.ALARM (ALRM), U1.11 (RA2)
CLOCK: JP1.CLK, U1.10 (SCL/RC0)
DAT: JP1.DAT, U1.9 (SDA/RC1)
DEBUGRX: JP2.2, U3.28 (DBG_RXD)
DEBUGTX: JP2.1, U3.27 (DBG_TXD)
GND: C2.2, C3.2, C4.2, C5.-, C6.2, CONN.UNUSED1 (SHIELD), CONN.UNUSED2 (SHIELD), JP1.GND, JP2.3, JP3.GND, R3.1, R4.1, R5.1, R6.1, U1.14 (GND), U3.17 (GND), U3.18 (GND), U3.29 (GND), U3.39 (GND), U3.45 (GND), U3.46 (GND), U3.53 (GND), U3.54 (GND), U3.58 (GND), U3.59 (GND), U3.61 (GND), U3.62 (GND), U3.63 (GND), U3.64 (GND), U3.65 (GND), U4.2 (GND)
unnamed: R3.2, U2.1 (R2)
unnamed: LED1.C, R6.2
unnamed: C1.2, R2.1, U2.6 (R1/C1)
unnamed: C1.1, FB-1.1, U2.2 (VOUT), U2.3 (VOUT)
unnamed: C6.1, U3.26 (VRTC)
unnamed: R1.1, U1.4 (MCLR)
unnamed: CONN.ANTENNA (PIN), U3.60 (ANT)
POW-SW-ON: R5.2, U1.3 (RA4), U2.5 (ON/OFF)
PWRKEY: U1.2 (RA5), U3.1 (PWRKEY)
RESET: U1.7 (RC3), U3.16 (RESET)
RXD: U1.6 (RC4), U3.10 (RXD)
SIMCLK: JP3.CLOCK (CLK), U3.32 (SIM_CLK), U4.5
SIMDAT: JP3.IO (DAT), U3.31 (SIM_DATA), U4.4
SIMRST: JP3.RESET (RST), U3.33 (SIM_RST), U4.3
SIMVCC: JP3.VCC, U3.30 (SIM_VDD), U4.1
STATUS: U1.8 (RC2), U3.66 (STATUS)
SW1: JP3.SW1, U1.12 (RA1)
SW2: JP3.SW2, R4.2, U1.13 (RA0)
TXD: U1.5 (RC5), U3.9 (TXD)
V+: JP1.4V, R2.2, U2.4 (VIN)
VCCINT: C3.1, JP1.V28 (2.8V), R1.2, U1.1 (VCC)
VDD: C2.1, C4.1, C5.+, FB-1.2, LED1.A, U3.55 (VBAT), U3.56 (VBAT), U3.57 (VBAT)
VDD_EXT: U3.15 (VDD_EXT)

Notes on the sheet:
Title:
Author:
Date:
Version:
Notes:
MoMo GSM Module
Tim Burke
9/22/2013
3 (modular, final)

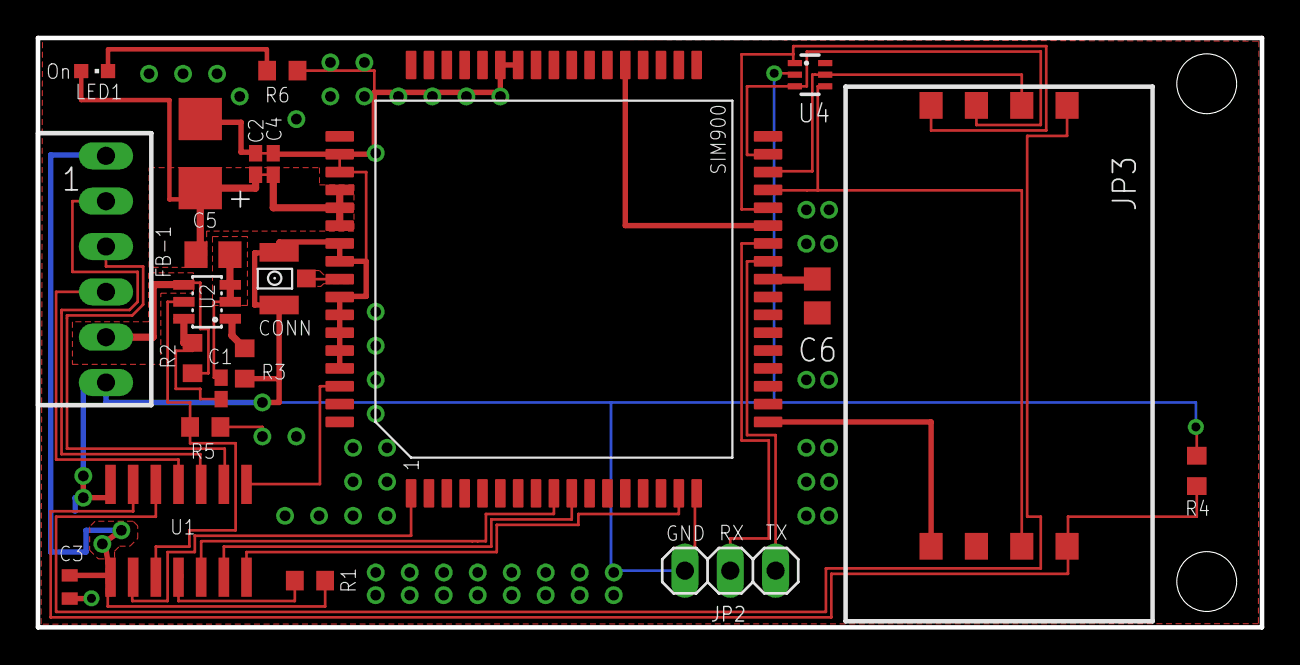
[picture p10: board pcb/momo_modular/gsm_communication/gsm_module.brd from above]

Board: 2 copper layers, 68.6 x 33.0 mm, 22 parts (0 on the bottom side), 28 nets.

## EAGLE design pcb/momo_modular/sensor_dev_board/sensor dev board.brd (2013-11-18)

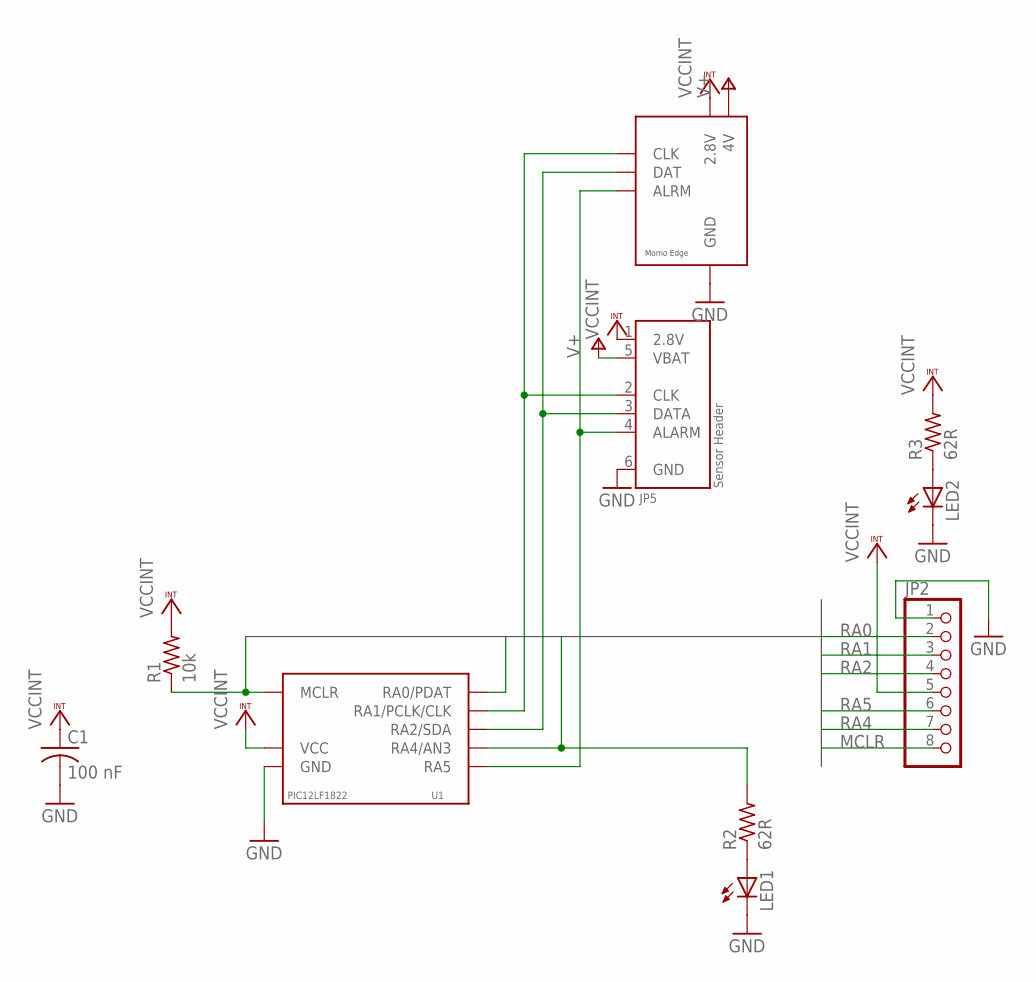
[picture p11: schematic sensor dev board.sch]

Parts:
C1: 100 nF; C0402; DIGIKEY-PN 445-1265-1-ND
JP2: PINHD-1X8; 1X08; DIGIKEY-PN S1012EC-08-ND
JP4: MOMO-VERT-6M; 1X06; DIGIKEY-PN S7004-ND
JP5: MOMO-SENSOR-RJ11; RJ-12
LED1, LED2: LEDCHIP-LED0603; CHIP-LED0603; DIGIKEY-PN 475-2709-1-ND
R1: 10k; R0603; DIGIKEY-PN P10.0KHCT-ND
R2, R3: 62R; R0603; DIGIKEY-PN P62GCT-ND
U1: PIC12LF1822; SOIC8; DIGIKEY-PN PIC12LF1822-I/SN

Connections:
GND: C1.2, JP2.1, JP4.7 (GND), JP5.6 (GND), LED1.C, LED2.C, U1.8 (GND)
MCLR: JP2.8, R1.1, U1.4 (MCLR)
unnamed: LED1.A, R2.1
unnamed: LED2.A, R3.1
RA0: JP2.2, U1.7 (RA0/PDAT)
RA1: JP2.3, JP4.3 (CLK), JP5.2 (CLK), U1.6 (RA1/PCLK/CLK)
RA2: JP2.4, JP4.4 (DAT), JP5.3 (DATA), U1.5 (RA2/SDA)
RA4: JP2.7, R2.2, U1.3 (RA4/AN3)
RA5: JP2.6, JP4.5 (ALRM), JP5.4 (ALARM), U1.2 (RA5)
V+: JP4.6 (4V), JP5.5 (VBAT)
VCCINT: C1.1, JP2.5, JP4.1 (2.8V), JP5.1 (2.8V), R1.2, R3.2, U1.1 (VCC)

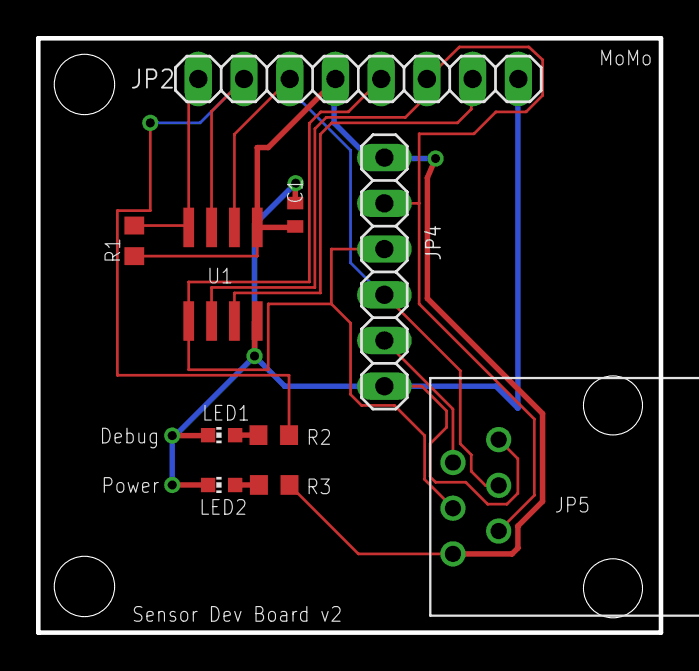
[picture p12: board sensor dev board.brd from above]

Board: 2 copper layers, 34.6 x 33.0 mm, 10 parts (0 on the bottom side), 11 nets.

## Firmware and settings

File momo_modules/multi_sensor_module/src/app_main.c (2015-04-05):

//app_main.c

#include "platform.h"
#include "watchdog.h"
#include "port.h"
#include "sample.h"
#include "mib12_api.h"
#include "log.h"
#include "digital_amp.h"
#include "watchdog.h"
#include "ioc.h"
#include "state.h"
#include "pulse.h" 
#include "alarm_repeat_times.h"

MultiSensorState state;

extern unsigned int adc_result;
extern uint8_t periods;

#define kMaxPeriods		10
uint16_t median_intervals[kMaxPeriods];

void task(void)
{ 
	wdt_disable();

	//If we slept for an increment, sample the number of pulses
	//Also allow pulse sampling if we received a sample command RPC
	if (nTO==0 || state.acquire_pulse)
	{
		pulse_sample();
		median_intervals[periods] = pulse_median_interval() >> 8; //divide by 256 to get approx in ms since each clock tick was 8 us
		state.acquire_pulse = 0;

		++periods;
	}

	if (state.push_pending)
	{
		uint16_t average_flow = 0;
		
		/*
		 * Compute and report the average flow rate in pulses per second
		 */
		if (periods > 0)
		{
			uint8_t i;

			for(i=0; i<periods; ++i)
			{
				if (median_intervals[i] > 0)
					average_flow += 1000UL/median_intervals[i];
			}

			average_flow /= periods;
		}

		state.push_pending = 0;

		bus_master_begin_rpc();
		mib_buffer[0] = mib_address;
		mib_buffer[1] = 0;

		mib_buffer[2] = 0;
		mib_buffer[3] = 0; //metadata

		mib_buffer[4] = average_flow & 0xFF;
		mib_buffer[5] = average_flow >> 8;
		mib_buffer[6] = 0;
		mib_buffer[7] = 0;

		bus_master_prepare_rpc(70, 0, plist_with_buffer(2, 4));
		bus_master_send_rpc(8);

		//Start counting again
		periods = 0;
	}

	WDTCON = k16SecondTimeout;
	wdt_enable();
}

void interrupt_handler(void)
{
	if (ioc_flag_b(PULSE_IOC))
	{
		if (PIN(PULSE_IN) == 0)
			pulse_falling_edge();
		else
			pulse_rising_edge();

		ioc_flag_b(PULSE_IOC) = 0;
	}
}

void initialize(void)
{
	PIN_DIR(VOLT1, INPUT);
	PIN_TYPE(VOLT1, ANALOG);

	PIN_DIR(VOLT2, INPUT);
	PIN_TYPE(VOLT2, ANALOG);
	
	ENSURE_DIGITAL(AN_POWER);
	LATCH(AN_POWER) = 0;
	PIN_DIR(AN_POWER, OUTPUT);

	ENSURE_DIGITAL(AN_SELECT);
	LATCH(AN_SELECT) = 0;
	PIN_DIR(AN_SELECT, OUTPUT);

	ENSURE_DIGITAL(AN_INVERT);
	LATCH(AN_INVERT) = 0;
	PIN_DIR(AN_INVERT, OUTPUT);

	ENSURE_DIGITAL(AN_PROG);
	LATCH(AN_PROG) = 0;
	PIN_DIR(AN_PROG, OUTPUT);

	PIN_TYPE(AN_VOLTAGE, ANALOG);
	PIN_DIR(AN_VOLTAGE, INPUT);

	ENSURE_DIGITAL(PULSE_IN);
	LATCH(PULSE_IN) = 0;
	PIN_DIR(PULSE_IN, OUTPUT);

	//Setup serial port
	ENSURE_DIGITAL(SERIAL_TX);
	LATCH(SERIAL_TX) = 1;
	PIN_DIR(SERIAL_TX, OUTPUT);

	ENSURE_DIGITAL(SERIAL_RX);

	damp_init();
	state.combined_state = 0;

	ioc_enable_b();
	periods = 0;
	
	bus_master_begin_rpc();

	mib_buffer[0] = mib_address;
	mib_buffer[1] = 0;

	mib_buffer[2] = 2;
	mib_buffer[3] = 20;

	mib_buffer[4] = kEveryMinute;
	mib_buffer[5] = 0;
	bus_master_prepare_rpc(43, 0, plist_ints(3));

	bus_master_send_rpc(8);
}

void main()
{

}

void check_v1()
{
	sample_v1();

	mib_buffer[0] = (adc_result & 0xFF);
	mib_buffer[1] = (adc_result >> 8) & 0xFF;

	bus_slave_setreturn(pack_return_status(0, 2));
}

void check_v2()
{
	sample_v2();

	mib_buffer[0] = (adc_result & 0xFF);
	mib_buffer[1] = (adc_result >> 8) & 0xFF;

	bus_slave_setreturn(pack_return_status(0, 2));
}

void acquire_voltage()
{
	damp_enable();
	sample_analog();
	damp_disable();

	mib_buffer[0] = (adc_result & 0xFF);
	mib_buffer[1] = (adc_result >> 8) & 0xFF;

	bus_slave_setreturn(pack_return_status(0, 2));
}

void set_damp_parameter()
{
	if (mib_buffer[0] >= kNumParameters)
	{
		bus_slave_setreturn(pack_return_status(6, 0));
		return;
	}

	damp_set_parameter((AmplifierSetting)mib_buffer[0], mib_buffer[2]);
	bus_slave_setreturn(pack_return_status(0, 0));
}

void power_analog()
{
	set_analog_power(mib_buffer[0]);
	bus_slave_setreturn(pack_return_status(0, 0));
}

void acquire_pulse()
{
	state.acquire_pulse = 1;
	bus_slave_setreturn(pack_return_status(0, 0));
}

void number_of_pulses()
{
	mib_buffer[0] = pulse_count() & 0xFF;
	mib_buffer[1] = pulse_count() >> 8;
	mib_buffer[2] = pulse_invalid_count() & 0xFF;
	mib_buffer[3] = pulse_invalid_count() >> 8;

	bus_slave_setreturn(pack_return_status(0, 4));
}

void read_pulse()
{
	uint8 pulse = mib_buffer[0];

	mib_buffer[0] = pulse_width(pulse) & 0xFF;
	mib_buffer[1] = pulse_width(pulse) >> 8;
	mib_buffer[2] = pulse_interval(pulse) & 0xFF;
	mib_buffer[3] = pulse_interval(pulse) >> 8;

	bus_slave_setreturn(pack_return_status(0, 4));
}

void scheduled_callback()
{
	state.push_pending = 1;
}

void read_periods()
{
	mib_buffer[0] = periods & 0xFF;
	mib_buffer[1] = periods >> 8;

	bus_slave_setreturn(pack_return_status(0, 2));
}

void set_push_status()
{
	state.push_disabled = !(mib_buffer[0] > 0);
	bus_slave_setreturn(pack_return_status(0, 0));
}

void read_median_interval()
{
	uint16_t median = pulse_median_interval();

	mib_buffer[0] = median & 0xFF;
	mib_buffer[1] = median >> 8;

	bus_slave_setreturn(pack_return_status(0, 2));
}

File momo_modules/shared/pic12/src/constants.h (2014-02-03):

/*
 * constants.h
 * All PIC12 special addresses and constant values that are shared between
 * the mib12 executive and mib12 application modules
 */

#ifndef __constants_h__
#define __constants_h__

/*
 * The MIB12 executive takes up the lower portion of memory.  Application modules
 * live in the higher portion of memory.
 */
#define kAppInitAddress			kFirstApplicationRow*kFlashRowSize
#define kAppInterruptAddress	kFirstApplicationRow*kFlashRowSize+1
#define kAppTaskAddress			kFirstApplicationRow*kFlashRowSize+2

/*
 * MIB12 Application Modules must define a special structure in the 16 high words of program
 * memory so that the mib12 executive can find information about the loaded application
 */
#define kMIBEndpointStructureSize (16)
#define kMIBEndpointAddress		0x800 - kMIBEndpointStructureSize
#define kMIBHWTypeOffset		0
#define kMIBTypeOffset			1
#define kMIBRevisionFlagsOffset	3
#define kMIBNameOffset			4

#define kMIBNumFeatureOffset	10
#define kMIBMagicOffset			15

#define kMIBMagicNumber			0xAA
#define kReflashMagicNumber		0x54

#endif

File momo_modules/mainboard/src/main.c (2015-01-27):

#include <stdlib.h>
#include "common.h"
#include "mainboard_reset_handler.h"
#include "task_manager.h"
#include "scheduler.h"
#include "memory.h"
#include "bus_master.h"
#include "report_manager.h"
#include <string.h>

// CONFIG4
#pragma config DSWDTPS = DSWDTPS1F      // Deep Sleep Watchdog Timer Postscale Select bits (1:68719476736 (25.7 Days))
#pragma config DSWDTOSC = LPRC          // DSWDT Reference Clock Select (DSWDT uses LPRC as reference clock)
#pragma config DSBOREN = ON             // Deep Sleep BOR Enable bit (DSBOR Enabled)
#pragma config DSWDTEN = OFF            // Deep Sleep Watchdog Timer Enable (DSWDT Disabled)
#pragma config DSSWEN = ON              // DSEN Bit Enable (Deep Sleep is controlled by the register bit DSEN)

// CONFIG3
#pragma config WPFP = WPFP63            // Write Protection Flash Page Segment Boundary (Page 52 (0xFC00))
#pragma config VBTBOR = ON              // VBAT BOR enable bit (VBAT BOR enabled)
#pragma config SOSCSEL = ON             // SOSC Selection bits (SOSC circuit selected)
#pragma config WDTWIN = PS75_0          // Watch Dog Timer Window Width (Watch Dog Timer Window Width is 75 percent)
#pragma config BOREN = ON               // Brown-out Reset Enable (Brown-out Reset Enable)
#pragma config WPDIS = WPDIS            // Segment Write Protection Disable (Disabled)
#pragma config WPCFG = WPCFGDIS         // Write Protect Configuration Page Select (Disabled)
#pragma config WPEND = WPENDMEM         // Segment Write Protection End Page Select (Write Protect from WPFP to the last page of memory)

// CONFIG2
#pragma config POSCMD = NONE            // Primary Oscillator Select (Primary Oscillator Disabled)
#pragma config BOREN1 = EN              // BOR Override bit (BOR Enabled [When BOREN=1])
#pragma config IOL1WAY = OFF            // IOLOCK One-Way Set Enable bit (The IOLOCK bit can be set and cleared using the unlock sequence)
#pragma config OSCIOFCN = ON            // OSCO Pin Configuration (OSCO/CLKO/RC15 functions as port I/O (RC15))
#pragma config FCKSM = CSECMD           // Clock Switching and Fail-Safe Clock Monitor Configuration bits (Clock switching Enabled and Fail-Safe Clock Monitor disabled)
#pragma config FNOSC = FRCPLL           // Initial Oscillator Select (Fast RC Oscillator (FRC))
#pragma config ALTVREF = DLT_AV_DLT_CV  // Alternate VREF/CVREF Pins Selection bit (Voltage reference input, ADC =RA9/RA10 Comparator =RA9,RA10)
#pragma config IESO = OFF               // Internal External Switchover (Disabled)

// CONFIG1
#pragma config WDTPS = PS32768          // Watchdog Timer Postscaler Select (1:32,768)
#pragma config FWPSA = PR128            // WDT Prescaler Ratio Select (1:128)
#pragma config FWDTEN = WDT_SW          // Watchdog Timer Enable (WDT controlled with the SWDTEN bit)
#pragma config WINDIS = OFF             // Windowed WDT Disable (Standard Watchdog Timer)
#pragma config ICS = PGx1               // Emulator Pin Placement Select bits (Emulator functions are shared with PGEC1/PGED1)
#pragma config LPCFG = OFF              // Low power regulator control (Disabled)
#pragma config GWRP = OFF               // General Segment Write Protect (Disabled)
#pragma config GCP = OFF                // General Segment Code Protect (Code protection is disabled)
#pragma config JTAGEN = OFF             // JTAG Port Enable (Disabled)

TaskManagerSleepStatus sleep_handler(TaskManagerCallbackReason task);

int main(void)
{
    register_reset_handlers();
    handle_reset();

    taskloop_set_sleephandler(sleep_handler);
    taskloop_loop();

    return (EXIT_SUCCESS);
}

TaskManagerSleepStatus sleep_handler(TaskManagerCallbackReason task)
{
	if (bus_master_idle())
	{
        if (taskloop_get_flag(kTaskLoopLightSleepBit) == 0)
		  mem_remove_power();
		
        return kCanEnterSleep;
	}

	return kCannotEnterSleep;
}

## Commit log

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2013-01-13 Fixed and added code to make the PIC work with the WISMO.
    [main.c]
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2013-03-12 Fixed ringbuffer code and made it useful, added taskloop code for autonomous cooperative multitasking (in initial testing phase), fixed reset_manager to control device initialization on reset
    [main.c]
2013-03-13 Updatd reset manager code and taskloop code. Began process of shifting main loop over to taskloop
    [main.c]
2013-03-14 Clean some stuff up, move GSM code to a modular and interface-agnostic location, start moving project defines to common.h so code doesn't hurt the brain organ as much. Aliased sends(U2,msg) to pring(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
    [main.c]
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2013-03-24 Add a memory self-test routine and call it on device reset (in configure_SPI). Better byte pretty-printing.
    [main.c, memory.c]
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2013-03-24 Scheduler module is working. Battery charging feature is working. It checks the battery voltage every 10 seconds and stops charging when the voltage is above 4.15V. It restarts charging when the volt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
    [main.c]
2013-03-24 Fixed SPI code to use correct clock polarity. The PIC output bits should transition on the falling edge of the clock signal since the memory clocks them in on the rising edge. This is SPI mode (1,1).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
    Memory test now passes, reading in the correct device serial number, family and size.
    [memory.c]
2013-03-25 Fix memory routines (working now). Data round-trips. Note that in order to write to memory, the section (or subsection) must have been cleared since the last write. Also fix atoi.
    [memory.c]
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2013-03-28 Started moving gsm code into gsm only section;always make sure secondary oscillator is enabled
    [main.c]
2013-03-28 Add basic sensor_event_log logic, improve report_manager and flash_queue, fix some memory bugs from a merge conflict introduced in feature-sensor-acquisition branch, clear out some warnings.
    [main.c, memory.c]
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2013-03-28 Rename initialization function to fit convention, fix integer overflow in sensor_event_log init call.
    [main.c]
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2013-03-31 Fix some gsm and memory bugs introduced by the merge. Tested persistent state logic.
    [memory.c]
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2013-06-16 MIB protocol code is at a useable level. The packet layer checks each packet for checksum errors and informs the rpc layer. The rpc layer is robust against transient errors. It automatically resends 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
    The code should be pretty stable at this point though and I envision relatively minor changes to it from now on.
    [main.c]
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2013-06-19 Fixed uart code for use with the FSU. Changed debug uart to U1 to correspond with connections on FSU. Isolated problem in UART transmission to ringbuffer issue. The ringbuffer seems to only return 0.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
    [main.c]
2013-06-20 Revert "Improved one trace to avoid 2 vias"
    This reverts commit defd9550a6ffd5e7c1ff802918ca0e38fc084f46.
    [controller.brd]
2013-06-20 Revert "Revert "Improved one trace to avoid 2 vias""
    This reverts commit 537d2f0d2fb6df7ee8012d30b8290097760d3c42.
    [controller.brd]
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2013-06-23 Laid out version 2 of the controller board and wall power board with better power supply layout to minimize noise coupling. Created version 1 of the gsm board. Changed Momo edge connector to an 8 pin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
    [controller.brd, gsm_module.brd, gsm_module.sch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]
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2013-07-01 Debugged pic12 slave code and verified that it works. Need further testing of edge cases but it correctly responds to feature/command requests and executes the command currently.
    [main.c]
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2013-07-13 Fixed bug where checksum errors would not be properly reported to mib.
    [main.c]
2013-07-13 Fixed addressing bug on the pic12 (do actually need to shift it 1 bit left).
    [main.c]
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2013-07-13 Finished reducing the size of the MIB code on the pic12 and its ram usage. It now fits in bank1 and common (<48 bytes). A little more work needs to done to make sure the compiled stack fits in common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
    [main.c]
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2013-07-16 Fixed Momo FSU MIB Code. Issue was manyfold: - bus_init(address) was bus_init(void) and apparently there's no warning so the address was silently ignored meaning all pic24s thought they were address 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
    I verified that rpc command sending now works.
    [main.c]
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2013-07-18 Reworked MIB Code to not send parameter headers with each parameter but rather to send a parameter spec that describes the parameters as a third byte in the bus command packet. The change is done on 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
    You don't have to call loadparams() anymore. Just use plist_set_int16(n, val)
    to set the values, fill the buffer if there is one and then call
    bus_master_rpc_async with the param_spec *including the length of the buffer*.
    This code is untested on pic24 but should work. Currently testing on
    pic12. Note you need to update the current endpoint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
    [main.c]
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2013-07-26 Added ability to send rpcs to different chips and fixed parameter verification bug on pic12.
    [main.c]
2013-07-30 First working version of the pic12 bootloader. It asks for firmware from the controller at the firmware endpoint and uses that to flash itself. I have confirmed that it flashes itself correctly. The 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
    [bootloader.h, main.c]
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2013-08-01 Acheived a working version of the pic12 mib executive and bootloader. The executive now can reflash new application code, check to see if a valid application is loaded (by looking for a magic number 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
    A skeleton application module is now available in mib12_sdk and the
    bootloader has been renamed to pic12_executive.
    Todos and caveats will be added and tracked in an issue on github.
    [app_main.c, bootloader.h, main.c]
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2013-08-06 Implemented automatic module registration on pic12. It enumerates itself to the pic24 controller, asks for an address and assigns that address to itself upon reception. This is tested and working. Th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
    [app_main.c, constants.h, main.c]
2013-08-12 Bugfixes for fsu and mainboard firmware pushing and current version of gsm module code.
    [app_main.c, main.c]
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2013-08-18 Fixed bug in bus_master where the receive buffer not being empty would cause the pic24 to incorrectly send an ACK when it wasn't supposed to.
    [app_main.c, main.c]
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2013-10-06 Revised combined controller board into what should be the final version. Added a current sense circuit to track battery charging, relaid traces out and swapped out the charger IC for a much cheaper o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
    Added a schottky diode on the input in all assembly variants to prevent reverse polarity charging and to prevent discharging into the charger if the charger loses power.
    [battery_controller.brd, battery_controller.sch]
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2013-11-01 updated board to have correct value for 51K resistor (wrong digikey part number)
    [battery_controller.brd, battery_controller.sch]
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2013-12-01 - Created template system using Cheetah library to allow creation of skeleton code for new MoMo modules. This will also be used for generating units tests in the future as well. - Implemented skeleto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
    [app_main.c]
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2014-01-02 Updated mib12_executive to support devices with more than 1 code page (i.e. we correctly protect ourselves against people changing the PCLATH register)
    [bootloader.h]
2014-01-15 Reworked MIB code to be more efficient by restructuring message protocol into a stateless protocol for the slave and a more streamlined protocol for the master. This leads to a dramaticaly reduced si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
    Greatly improved test coverage of MIB12 code including simulated slave calls using a
    bit-banged i2c implementation as a gpsim stimulus to verify that everything is working
    correctly. Next step is to implement a MIB responder as a gpsim module in order to allow more
    thoug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
    [bootloader.h, main.c]
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2014-02-07 Fix mib12_executive bootloader bugs and finish registration
    - some bugs crept in during the conversion of the mib12_executive
    from primarily c to primary assembly. Fixed them and verified
    correct programming on 16lf1847.
    - replaced registration function with optimized asm version
    takes up less space and is more robust. Uses asm memcpy function
    to pull data from application code.
    [main.c]
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2014-02-07 Fixed bugs in pv_module, added debug mib endpoints
    There was a random bit being or'ed in with one of the voltage
    measurements. Unclear why I put it there. I think it was to
    test that the fat32 code was write something other than zeros
    but it never got removed and only shows up when measuring low
    voltages.
    Added mib endpoints for sampling v1, v2, v3, i1 for debugging.
    [app_main.c]
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2014-02-20 Finalize combined controller layout
    - Switch power connector to one that doesn't require a board cutout
    - Relay out traces better given that we note have more space
    - Make the board a regular shape
    [combined_controller.brd, combined_controller.sch]
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2014-02-23 Reclock controller down to 8mhz
    This avoids using the 4x PLL for lower power consumption and
    faster wakeup from sleep since we don't have to wait for the
    PLL to stabilize
    [main.c]
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2014-02-23 Fix flash writes to allow crossing page boundaries
    Added memory_write_aligned that writes at most a single aligned
    page of flash.
    Replaced memory_write with a version that internally divides the
    passed in buffer into page aligned portions and calls memory_write_aligned
    for each one in turn.
    [memory.c]
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2014-02-26 Refactor firmware_cache and persist in flash
    - uses new flash_block system to simply persist state across resets
    - can now store and read flash images across resets
    - reduced memory footprint by removing redundant variables
    [firmware_cache.h]
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2014-03-04 Fix gsm layout based on measured SIM900 module size.
    U1 and C5 would be very close to the module so I relaid it out in
    order to maximize the distance between the SIM900 and those two
    components. Also, C5 was swapped for a smaller tantalum capacitor
    since the ripple current was calculated too conservatively last time.
    [gsm_module.brd, gsm_module.sch]
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2014-03-12 Fix error branching to bootloaded code.
    The bootloader now works correctly but requires a direct branch
    to the bootloaded code at 0x200 rather than an intermediate step
    where the start vector is copied to 0x100 (a reserved location).
    The PIC cannot handle a jump to the reserved location however. I
    do not know why but this is reproducible even by hardcoding such a
    jump into the mainboard code. The current method works fine and
    the bootloader is now finished.
    [main.c]
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2014-03-12 Fix gsm module to not have sim card adapter hang over board edge
    - This would have meant that the board could not be routed post
    smt assembly and that the board could not have been panelized at
    2x1.3" since the part would not have been assemblable.
    - As a consequence, I had to get rid of the screw holes for this
    module.
    [gsm_module.brd, gsm_module.sch]
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2014-03-20 Update MoMo FSU with modular connector
    - relay out to fix Polycase USB-31 case.
    - board is finished and ready for fabrication
    [programming_board.brd, programming_board.sch]
2014-03-23 Fix bootloader code to not have a hardcoded reset vector
    This reset vector can and apparently does change frequently so
    fetch it by reading the first 2 words of flash.
    [bootloader.h, constants.h]
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2014-03-26 Make the GSM interface more robust. TODO: message sending can fail silently, timouts *shouldn't* happen for successful commands but it's possible they could, causing an RPC 6 (unknown) error response.
    [app_main.c]
2014-03-31 Finish v1 of multi_sensor board
    Board is based on the elec_sensor_sd board previously made but with
    the following changes:
    - removed SD card b/c of space
    - added sensors
    + pulse counting (turbine flow sensor)
    + 3 voltages from 0-30V
    + 1 current from 0-15A
    + external serial connection bidirectional and 5V tolerant
    + wheatstone bridge sensor connection
    + differential analog voltage
    + pressure sensor (SM5470 for venturi sensing)
    All of the analog sensors are built around a digitally controllable
    instrumentation amplifier AD8557. It's a pricey part but should
    give us a lot of flexibility for retargeting the board in the future
    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
    [multi_sensor.brd, multi_sensor.sch, sensor_elec_sd.brd]
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2014-04-12 Update bootloader to work with new board.
    - now waits for ALARM pin to be released before starting a reflash.
    This fixes a bug with using Pickit3 to program the bootloader where
    the bootloader would trigger immediately after being programmed
    - updated SPI flash to full-speed. There was no reason to be using
    it at 1/512th speed.
    - communication with main controller firmware is now done not with
    EEPROM but a perisistent global variable. The new chip has no EEPROM
    [bootloader.h, constants.h, main.c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]
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2014-04-12 Update controller code for new board.
    - RTCC lives forever now with the backup battery, so
    don't reset it on a power-on reset
    - reflash endpoint now uses shared global variable to communicate
    with bootloader rather than flash.
    - updated linker script with new memory map for new chip
    [main.c]
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2014-04-16 Update pic12 executive to not boot apps on ALARM
    You can now force all of the mib modules to not start
    running user code if ALARM is low on reset.
    [main.c]
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2014-05-16 Significantly improve GSM command handling by adding a rotating RX buffer, improved timeout behavior, less restrictive response matching, and autonomous reporting behavior (meaning the radio is turne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
    [app_main.c]
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2014-05-19 Capture the OK (or error) after closing the stream, don't shutdown the module on an error (yet) since we want to capture the error code.
    [app_main.c]
2014-05-21 Implement module iteration based on defined type, change type definitions to be a bitset so a module can have multiple functions, send reports to all attached comm modules, wait until we've received 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
    [app_main.c]
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2014-05-26 Compact executive, add trap() and test for dirty reset
    - Added API call trap that will take control and loop forever like a
    kernel panic. This lets you attach with a debugger over MIB.
    - Added check for dirty resets. A dirty reset is one that does not use
    the reset() function. A poison bit is set upon startup that is cleared
    in the reset API function. Otherwise the executive will trap upon reset,
    after reregistering so that it has a valid address for debugging.
    [bootloader.h, main.c]
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2014-05-28 Modify bootloader to pull alarm low during reflash
    - reflashing error on pic16lf1847 was due to modtool not waiting long
    enough for all 8KB to be reflashed. The wait time was hard-coded
    for 4KB, hence when all the application fit in the first 4KB there
    were no issues.
    - now the pic12_executive pulls the alarm pin low during reflash so
    that modtool knows exactly how long to wait before resetting the
    bus.
    [main.c]
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2014-05-30 Add some more error case checking. Don't allow multiple streams to be started (TODO: turn off the module if a stream is opened but never closed). Remotely log errors if a message fails to send.
    [app_main.c]
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2014-06-06 Wait longer for network detection and message reception, actually exit with an error if we fail to register, wait longer after starting the SMS stream (for some reason Vodacom SIMs were taking longer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
    [app_main.c]
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2014-06-08 Update Controller Board Layout
    - add sense line for external power
    - move components for easier placement
    - reroute long lines
    - flip backup battery orientation to allow for easy insertion
    - move cap away from crystal to avoid shorts
    [combined_controller.brd, combined_controller.sch]
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2014-06-09 Fix multisensor board layout
    - Add separate power supply for analog circuitry to
    maintain voltage requirement.
    - Fix data line connection on MIB bus
    - Remove incorrect pin headers
    [multi_sensor.brd, multi_sensor.sch]
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2014-06-09 Fix screw hole positions to match polycase and be symmetrical
    Actual screw spacing should be 3.744" not 3.8".
    [combined_controller.brd, gsm_module.brd]
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2014-06-10 Add interrupt protection to flash memory routines
    Flash routines should not be interrupted during the time
    that they are writing to the flash RAM. This could cause
    timing issues if a command is only partially sent and then
    interrupted.
    [memory.c]
2014-06-10 Update critical section to not include chip warmup wait time
    This avoids the ~30 ms delays when waiting for the flash chip
    to stabilize for writing. The read stabilization calls are
    still inclued in the critical section since they are at most 1ms.
    [memory.c]
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2014-06-14 Add 10 us low alarm pulse resets all slaves.
    - Reimplement bus slave logic in assembly for optimized size
    - Changed several functions to indicate return value using status
    bits like ZERO for optimized checks.
    - Implemented bus_slave_callhandler in assembly
    [main.c]
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2014-06-17 Remove alarm check for running application code
    Upon ALARM assertion, all modules will reset automatically based
    on the IOC interrupt implemented on the ALARM pins, so there is
    no possibility of running application code (or any code) while the
    alarm pin is down.
    [main.c]
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2014-06-24 Add profiling and fix giant performance problem
    Due to the way the SPI peripheral was initialized, it was not running
    at full speed. Evidently, you must set the SPI clock frequency
    before setting the SPIEN bit to enable the module. Failing to do
    this causes the setting to be ignored. This manifests in reading and
    writing from flash taking between 3 and 10 times longer than necessary
    and causing performance issues in construct_report as well as making
    modtool reflash run very slowly.
    Using the new perf module, I tracked this down and fixed it.
    [memory.c]
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2014-06-25 Update peripheral pin mapping to map SCK as IN/OUT
    Per the datasheet on the chip, you must map SCK as both an input
    and an output. I don't think this has caused any issues so far
    but it's better to comply with the spec than not to.
    [memory.c]
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2014-07-21 Fix some issues with report retry beavior, support reading report log from the command line.
    [app_main.c]
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2014-07-21 Delay shutting off GSM module until after we've reported success or failure.
    [app_main.c]
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2014-07-22 Report error messages again and fix the param spec for the failure notification MIB endpoint.
    [app_main.c]
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2014-09-29 Update pic24 library to be slimmer on pic24f16ka101
    Current version include many mainboard specific routines like
    system_log, flash_queue and flash_block that require a flash memory
    chip. The FSU does not have one so it cannot use these routines.
    The routines were making the code size too big to fit on the chip.
    [memory.c]
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2014-10-12 Update pic12_executive and gsm_module to use local build settings
    - Modify scons to allow local build settings for pic12 modules
    - Add settings for gsm_module and pic12_executive
    - Fix unit testing to show proper target names
    Update gsm_module to target both pic16lf1847 and pic16lf1823
    - Update pin locations to be in module_settings.json
    - Create port_definitions.h shared file that knows which pins can be made analog or not
    so that we can safely try to make a pin analog or digital even if that pin does not support
    it on a specific chip but the failure is not important. Without this we get compilation
    errors because the right analog register doesn't work.
    Bugfixes for GSM module
    - Update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
    [app_main.c]
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2014-10-25 Update pcb build system and bugfixes
    - support finding eagle via path
    - support automatic creation of Diode Descriptions
    Update controller board to rev 4.0.
    - New version contains BTLE via Microchip RN4020 module
    - Voltage supervisor with hard reset capability from bluetooth
    or via microcontroller
    - Current monitor for solar and external charging current
    - Move 2.8V linear regulator and add RF filtering caps to fix RF
    interference problems on GSM transmission.
    Rename combined_controller to controller
    We don't have different assembly variants anymore so the
    combined isn't needed.
    [combined_controller.brd, combined_controller.sch]
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2014-12-08 Merge pull request #141 from timburke/pr-controller-v4
    Update Controller Hardware to Version 4.0
    Merge pull request #141 from timburke/pr-controller-v4
    Update Controller Hardware to Version 4.0
    o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
    [controller.brd, controller.sch, controller_part_sizing.xlsx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]
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2015-01-10 Refactor the internal GSM module api for serial communication with the SIM900, and implement GPRS reporting.
    Specifically:
    - Implement basic multi-server report failover
    - Update GSM module code to work better with the new hardware
    - Update the xc8 1.33 download hash.
    - Remove non-working intelhex test.
    - Remove the 'asm' compiler optimization for gsm_module - it was causing weird logic errors
    - Implement bimodal comm streaming (sms and GPRS/http)
    - Change the comm stream api to accept a destination separately (using a new set_comm_destination RPC) and accept a length when opening a stream.
    - Don't retry reports that weren't initiated by the controller.
    [app_main.c]
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2015-01-22 Support fully running executive in gpsim. Support fully running pic12_executive in gpsim
    Update with new IOC code that works on all platforms
    Add ability for unit tests to find support files per architecture
    This means that the same unit test that needs, for example, signals
    wired to different pins on each architecture doesn't need a separate
    unit test file for each architecture. Instead it just includes a
    support file without an architecture extension and the build system
    searches for the appropriate support file for that architecture
    automatically.
    Fix bug in prefix handling and write documentation
    Update to not have reflash reset problem
    Fix merge error
    Fix incorrect macro usage in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
    [bootloader.h, main.c]
2015-01-27 Add ability to build shared library without uart interrupts.
    Add ability to build shared library without uart interrupts.
    Update mainboard with first version of btle code
    Update library port module and add timer module.
    Update bootloader to support new controller version.
    Allow for easy modification of pin assignments and demonstrate btle
    Bugfix build system and update rn4020 to advertise itself.
    Add pinout for v41 of the hardware.
    Update battery to handle logic for controlling charging
    Working code for new hw.
    Add code to force rn4020 into 38400 baud mode
    - reset oscillator back to 8 Mhz mode
    - update code to allow for switching to 32 Mhz mode
    - write logic for switching oscillato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
    [bootloader.h, constants.h, main.c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]
2015-02-10 Fix all things GSM.
    - Update gsm board to fix issues
    - Recognize roaming registration as well as local registration
    - Fix initialization order for syslog
    - Implement unit testing for gsm module
    - Reclock down to 19200 baud so we don't miss characters
    - Implement buffer and gsm_rx logic in assembly
    - Update linear address space to not conflict with other variables
    - Diagnoze and work around the most terrible XC8 compiler bug in the whole world
    - Detect GSM band and attempt to optimistically select it for subsequent registrations
    - Implement MoMo controller UUID storage, include that UUID in reports, and also timestamp each report explicitly
    - Move all gsm logic to interrupt code to avoid anno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
    [app_main.c]
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
